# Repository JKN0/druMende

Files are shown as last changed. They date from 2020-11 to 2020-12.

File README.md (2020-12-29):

# druMende

Drumende is an analog drum machine in 70's style. All circuitry is designed so that it could have been built in the late 70's/early 80's.
All sound generators are analog, using transistors and op amps. Sequencer is without microcontroller, only 7400/4000-series discrete logic.

Soundgenerators are modeled according to classic drum machines and also newer designs:
- Boss DR-55: bass drum, snare drum, hi-hat, accent-circuit
- Korg KR-55: bass drum, snare drum, rimshot, claves, noise generator
- Andromeda Space Rockers by Eric Archer: hi-hat, tom hi, tom lo
- 7400 contest entry by Matt Sarnoff: sequencer

The goal has not been to duplicate the original circuits as close as possible. There are several modifications to original circuits.
Also sequencer has experienced serious modifications.

There are 10 sound generators. Because sequencer has only 6 voice channels + accent channel, sound for four channels is selectable.
Each channel level can be controlled with level control knobs. Also each channel has one controllable parameter, tuning or decay time.

Sequencer is 7 channel, 16 steps. Two 7 x 16 step patterns can be stored.

Demonstration video: https://youtu.be/f7uYuddqCkw

A more detailed build log is here: https://retroandreverse.blogspot.com/2020/12/analog-drums-beginnings-drumshave.html

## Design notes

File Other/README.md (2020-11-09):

# Audio and power

Enclosure for the drum machine is Nordmende Fidelio table radio from the 70's. 
Radio's audio amplifier and mains transformer are used as a part of the design.

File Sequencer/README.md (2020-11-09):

# Sequencer

Sequencer is  divided to two circuit boards

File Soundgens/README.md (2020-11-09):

# Sound generators

Sound generators are divided in four circuit boards:

- DR-55 soundgen
-- 3 generators: DR-55 BD, SD, HH
- KR-55 soundgen
-- 3 generators: KR-55 BD, SD; ASR MK2 HH
- Perc soundgen
-- 4 generators: KR-55 rimshot, claves; ASR MK1 hi-tom, lo-tom
- Main mixer
-- main mixer, accent submixer, accent circuit, noise generator

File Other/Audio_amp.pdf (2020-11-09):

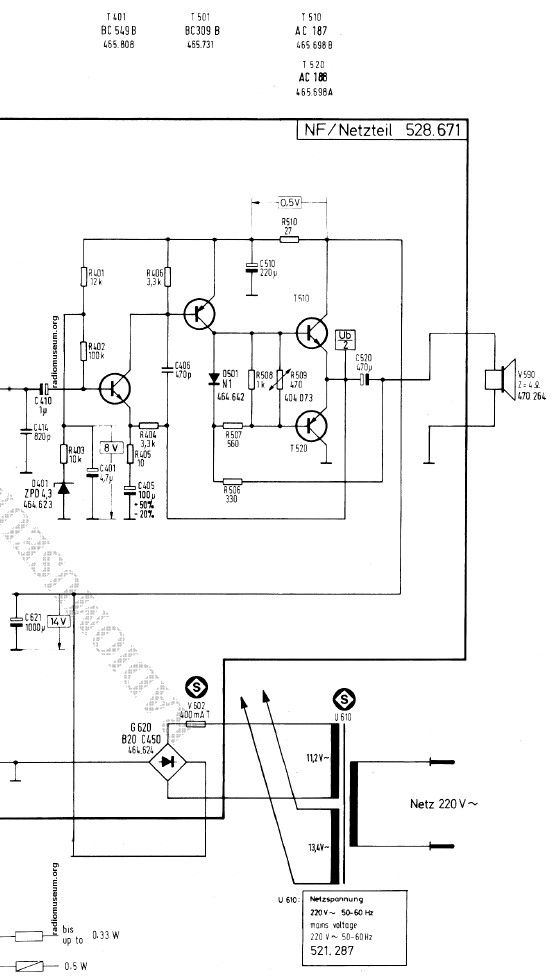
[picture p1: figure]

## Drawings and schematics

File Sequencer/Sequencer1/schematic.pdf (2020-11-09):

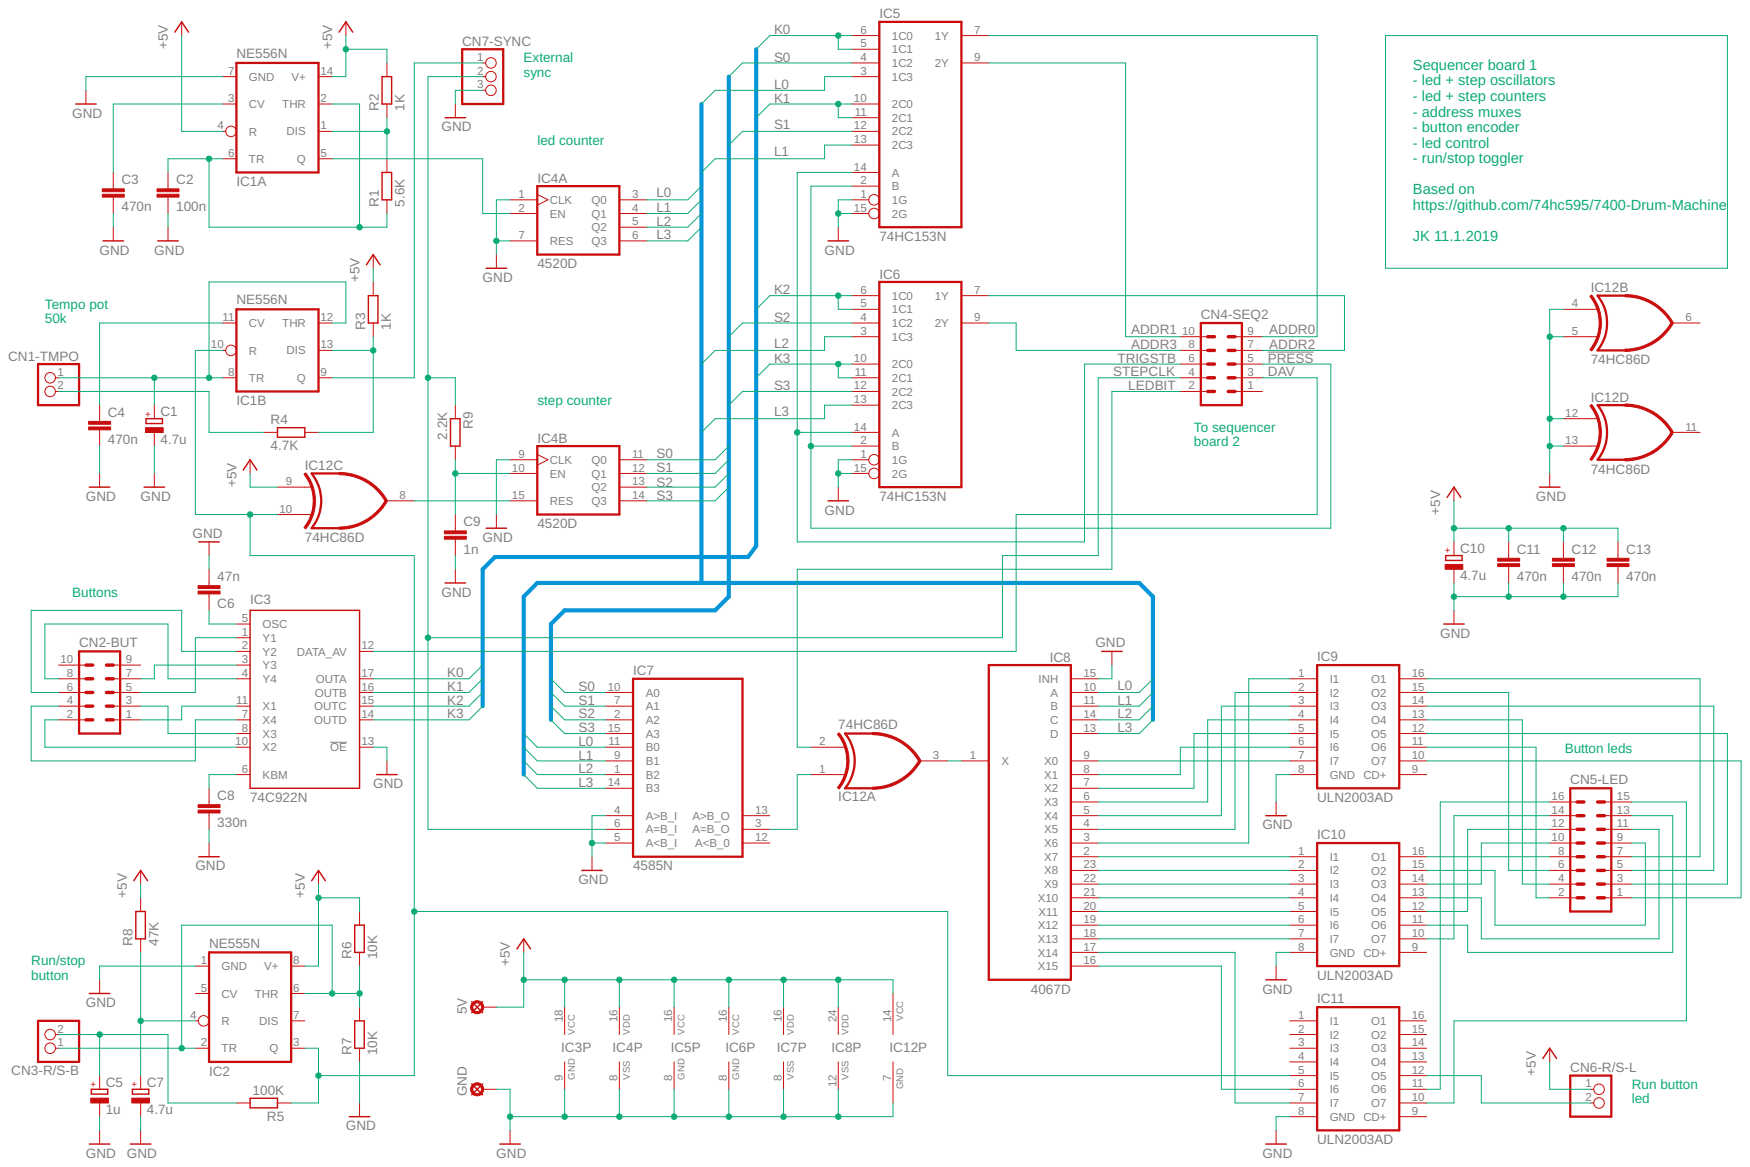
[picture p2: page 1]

Sequencer board 1
- led + step oscillators
- led + step counters
- address muxes
- button encoder
- led control - run/stop toggler Based on

https://github.com/74hc595/7400-Drum-Machine

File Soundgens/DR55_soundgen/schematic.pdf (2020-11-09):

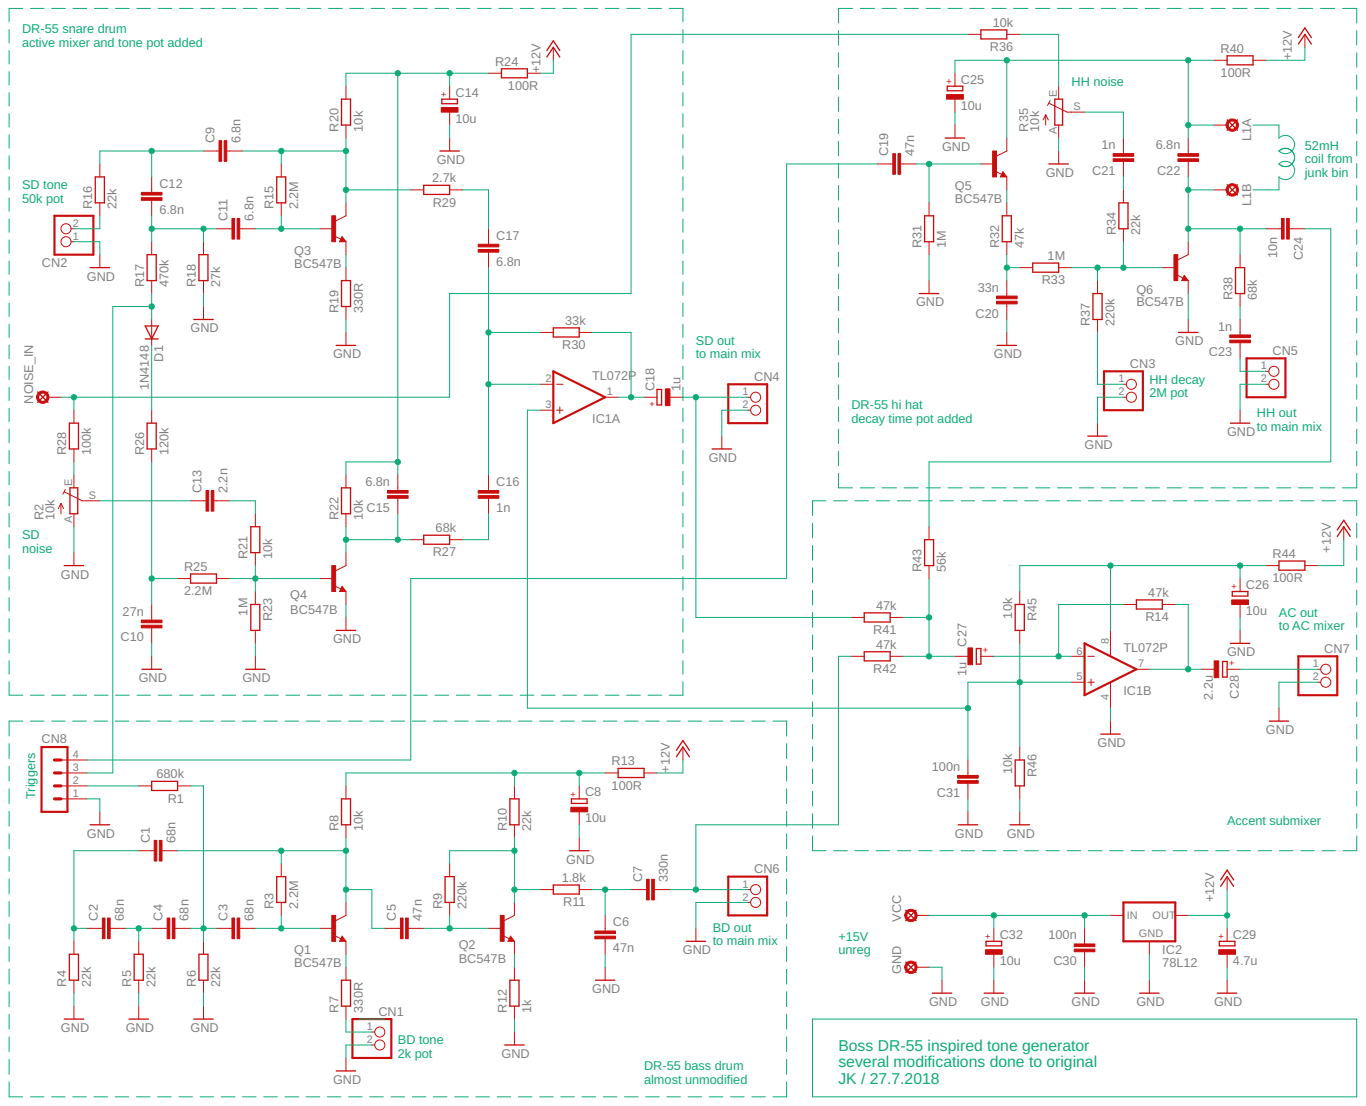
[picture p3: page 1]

DR-55 snare drum
active mixer and tone pot added

DR-55 hi hat decay time pot added

10k GND GND GND GND GND GND

Boss DR-55 inspired tone generator several modifications done to original

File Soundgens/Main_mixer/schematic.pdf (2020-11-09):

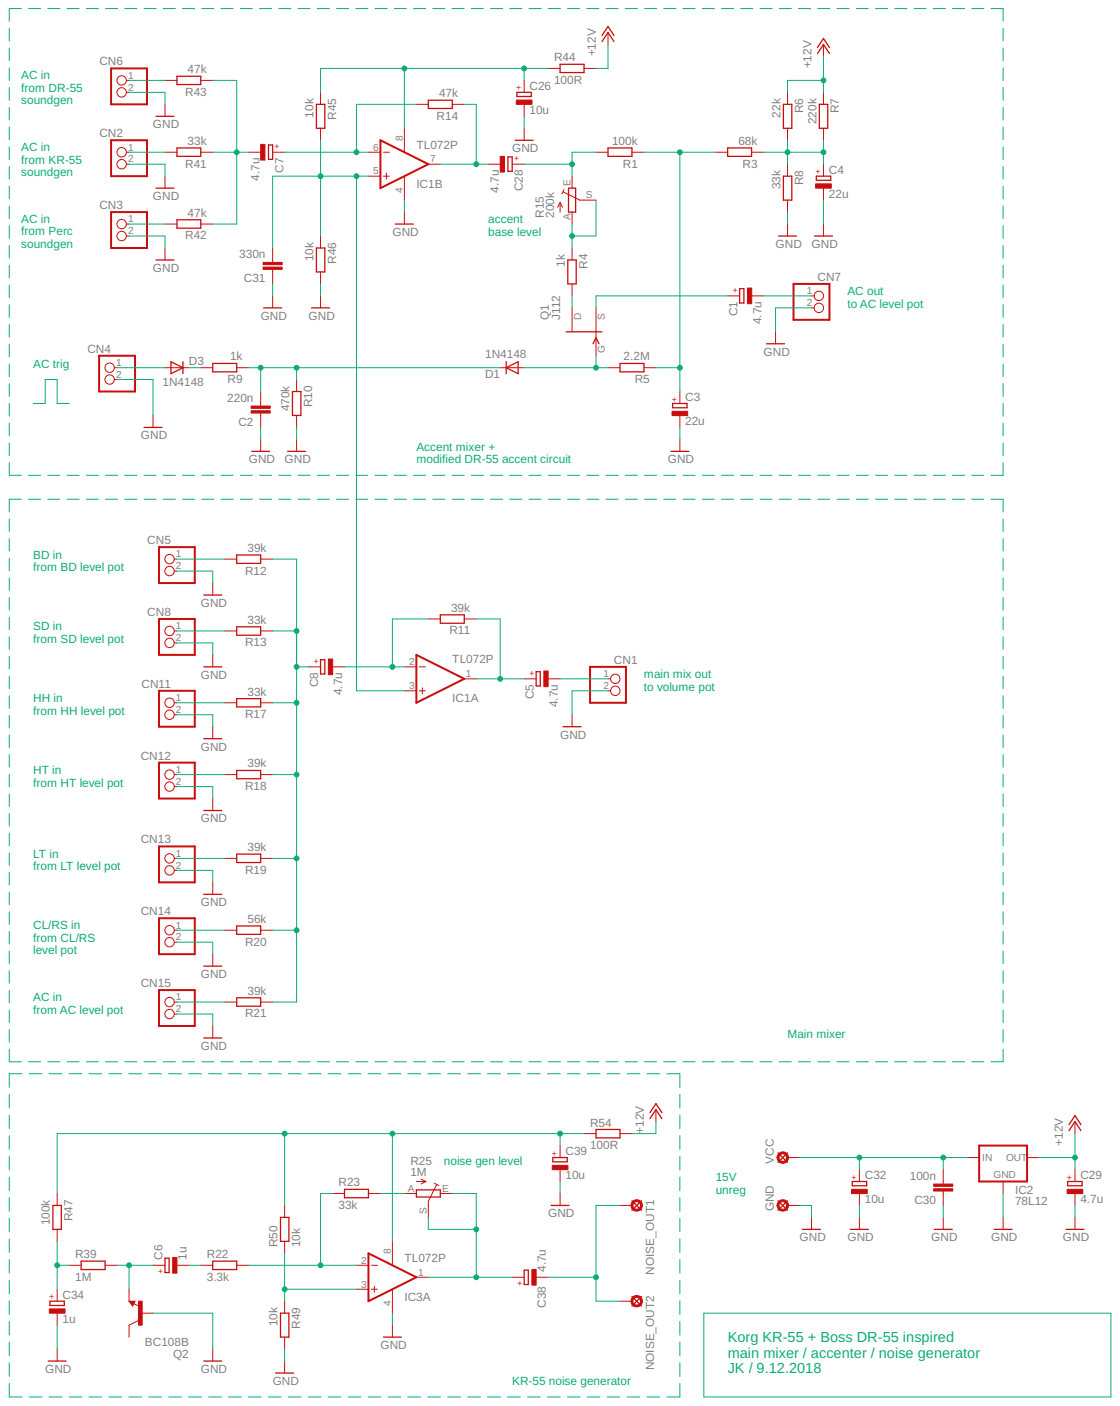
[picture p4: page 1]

AC out
to AC level pot

Accent mixer + modified DR-55 accent circuit

from BD level pot

from SD level pot HH in

from HH level pot HT in

from HT level pot LT in

from LT level pot CL/RS in

from CL/RS
level pot AC in

Korg KR-55 + Boss DR-55 inspired main mixer / accenter / noise generator JK / 9.12.2018

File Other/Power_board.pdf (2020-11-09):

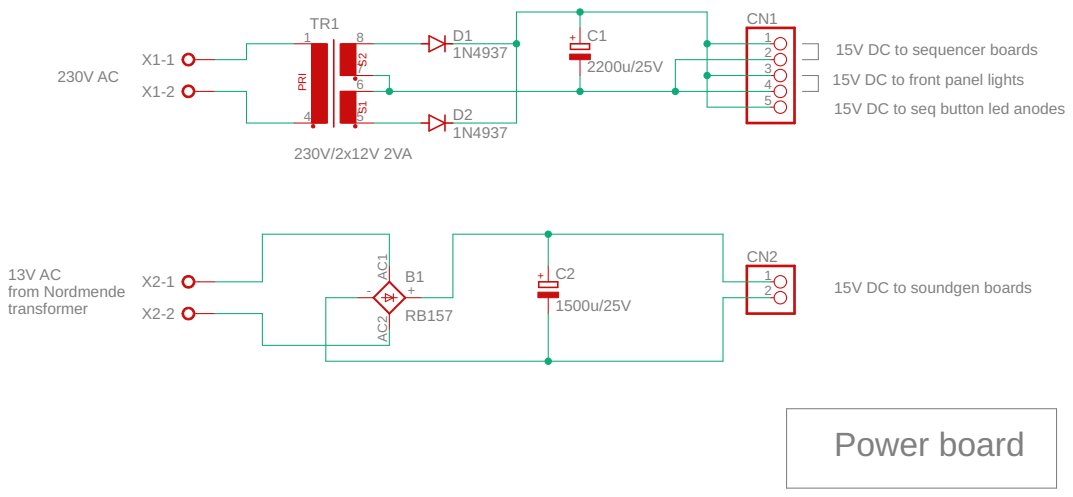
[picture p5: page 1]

15V DC to front panel lights 15V DC to seq button led anodes 15V DC to sequencer boards

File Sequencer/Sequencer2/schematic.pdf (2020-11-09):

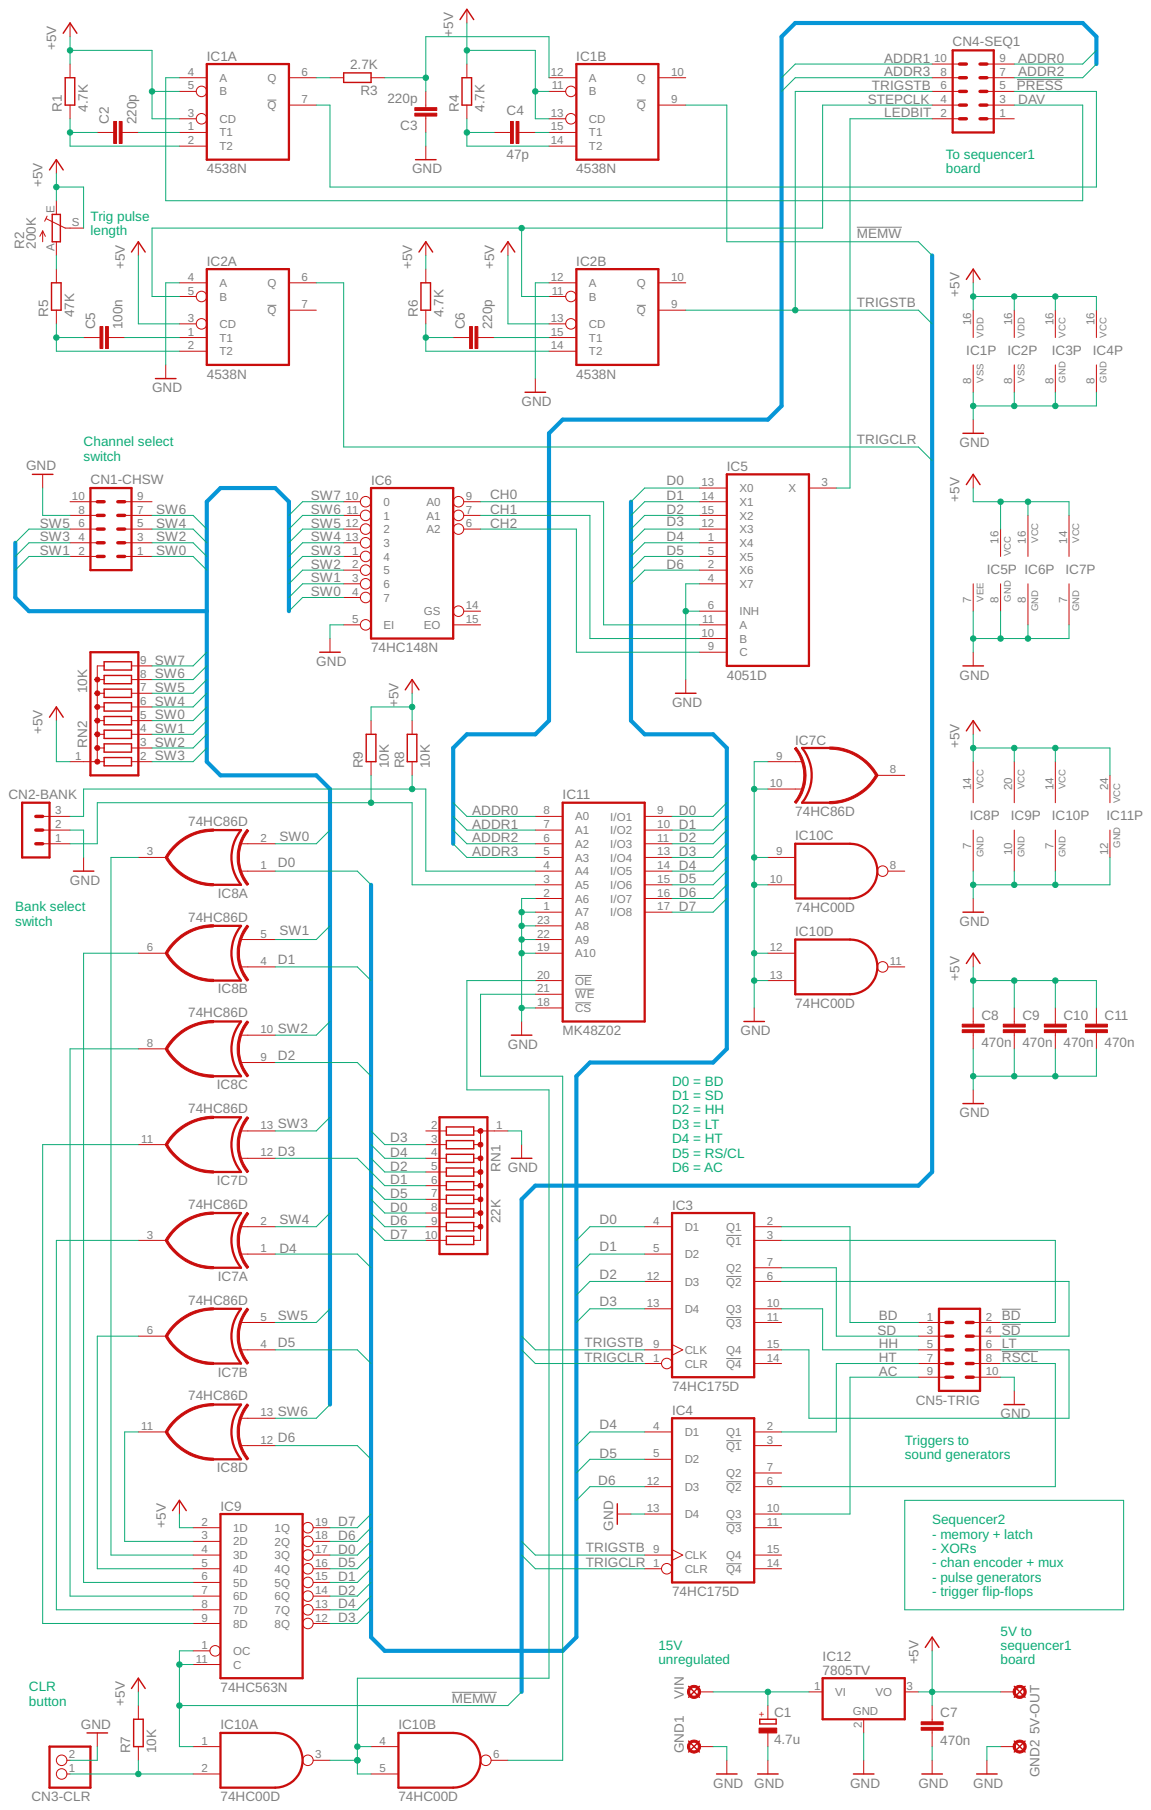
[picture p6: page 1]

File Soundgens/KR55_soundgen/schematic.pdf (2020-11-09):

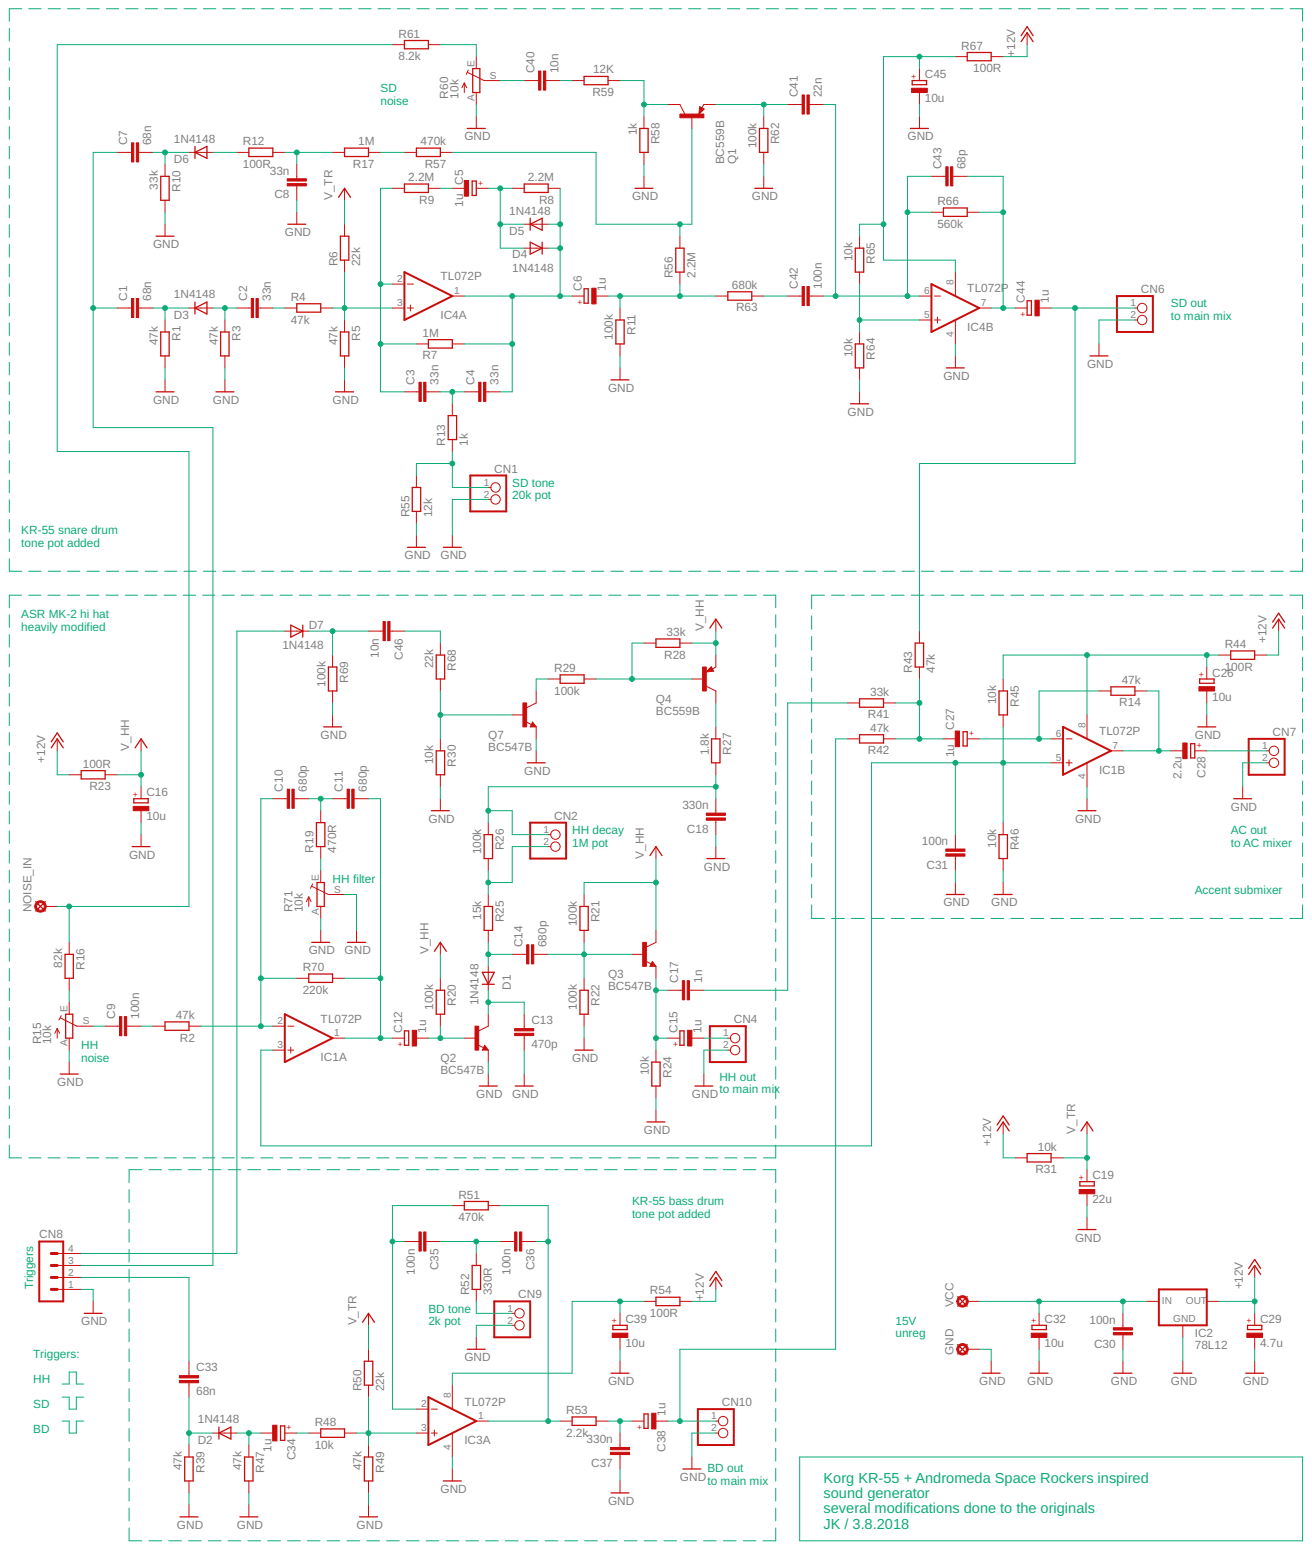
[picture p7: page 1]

KR-55 snare drum
tone pot added ASR MK-2 hi hat heavily modified

Korg KR-55 + Andromeda Space Rockers inspired
sound generator several modifications done to the originals

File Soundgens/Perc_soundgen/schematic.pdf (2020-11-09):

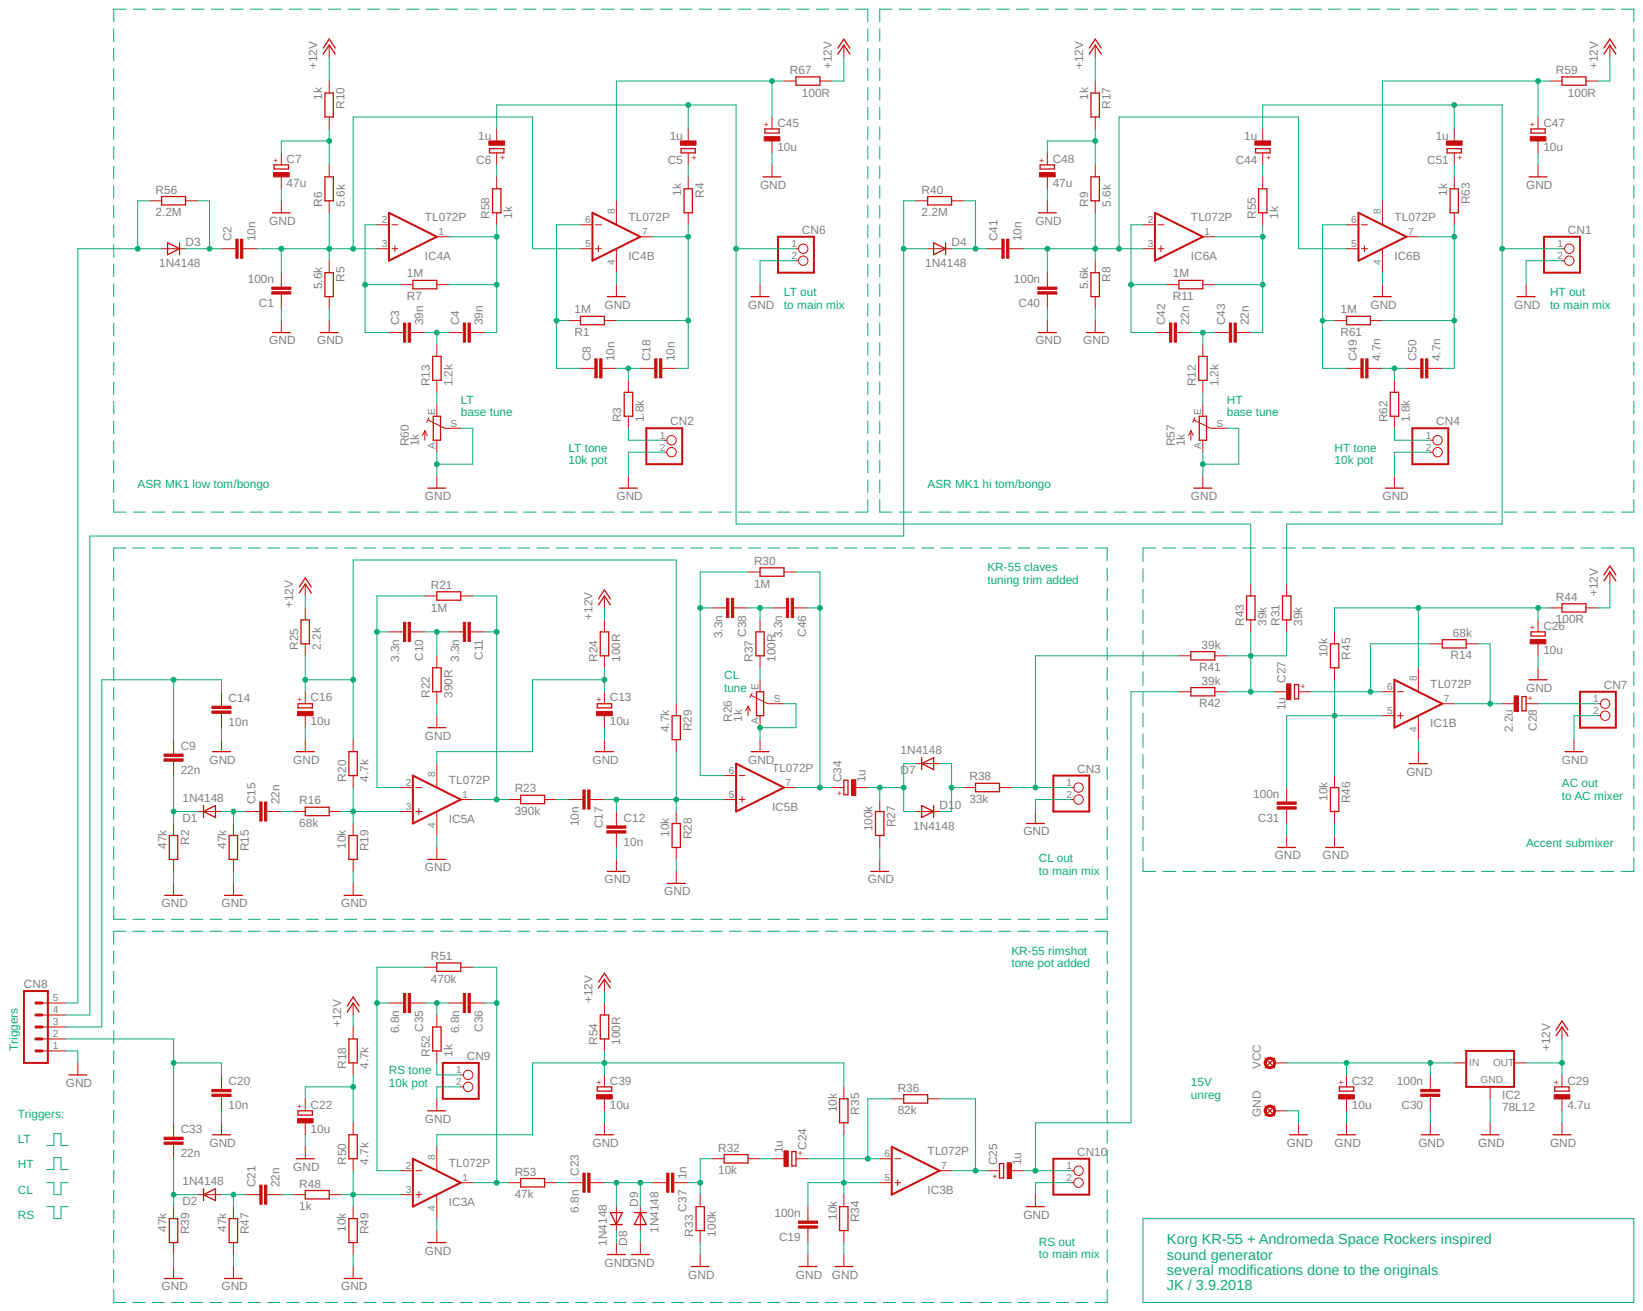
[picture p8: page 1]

ASR MK1 low tom/bongo

Korg KR-55 + Andromeda Space Rockers inspired
sound generator several modifications done to the originals

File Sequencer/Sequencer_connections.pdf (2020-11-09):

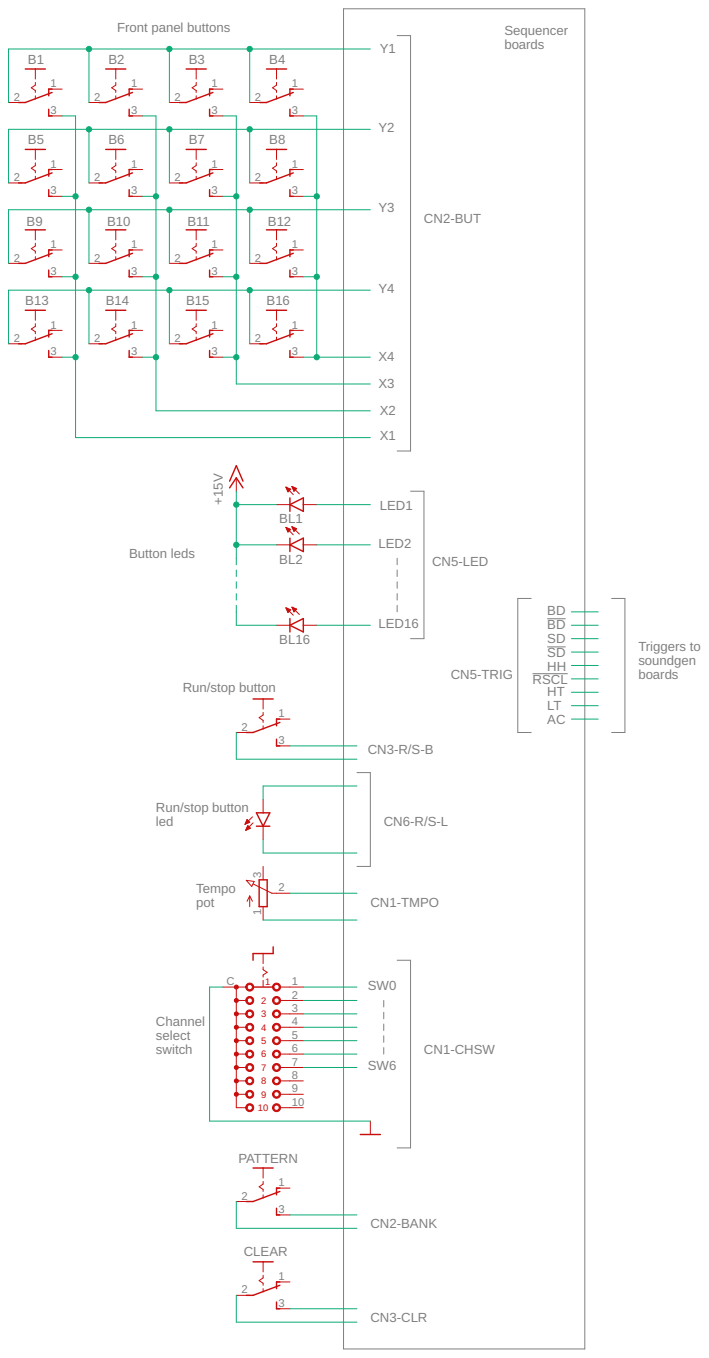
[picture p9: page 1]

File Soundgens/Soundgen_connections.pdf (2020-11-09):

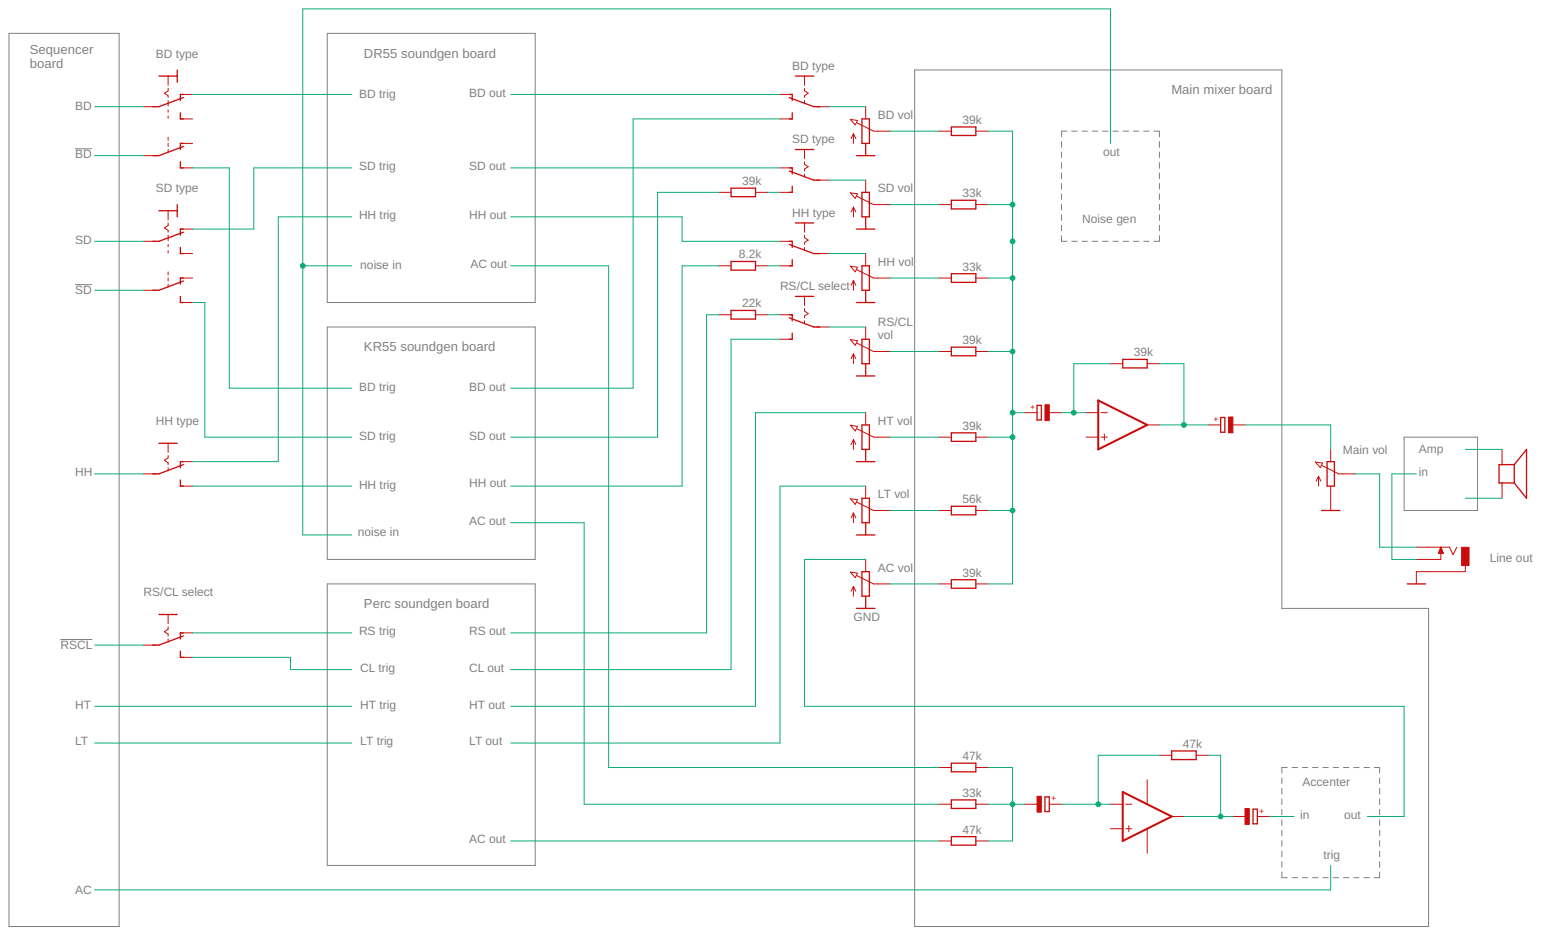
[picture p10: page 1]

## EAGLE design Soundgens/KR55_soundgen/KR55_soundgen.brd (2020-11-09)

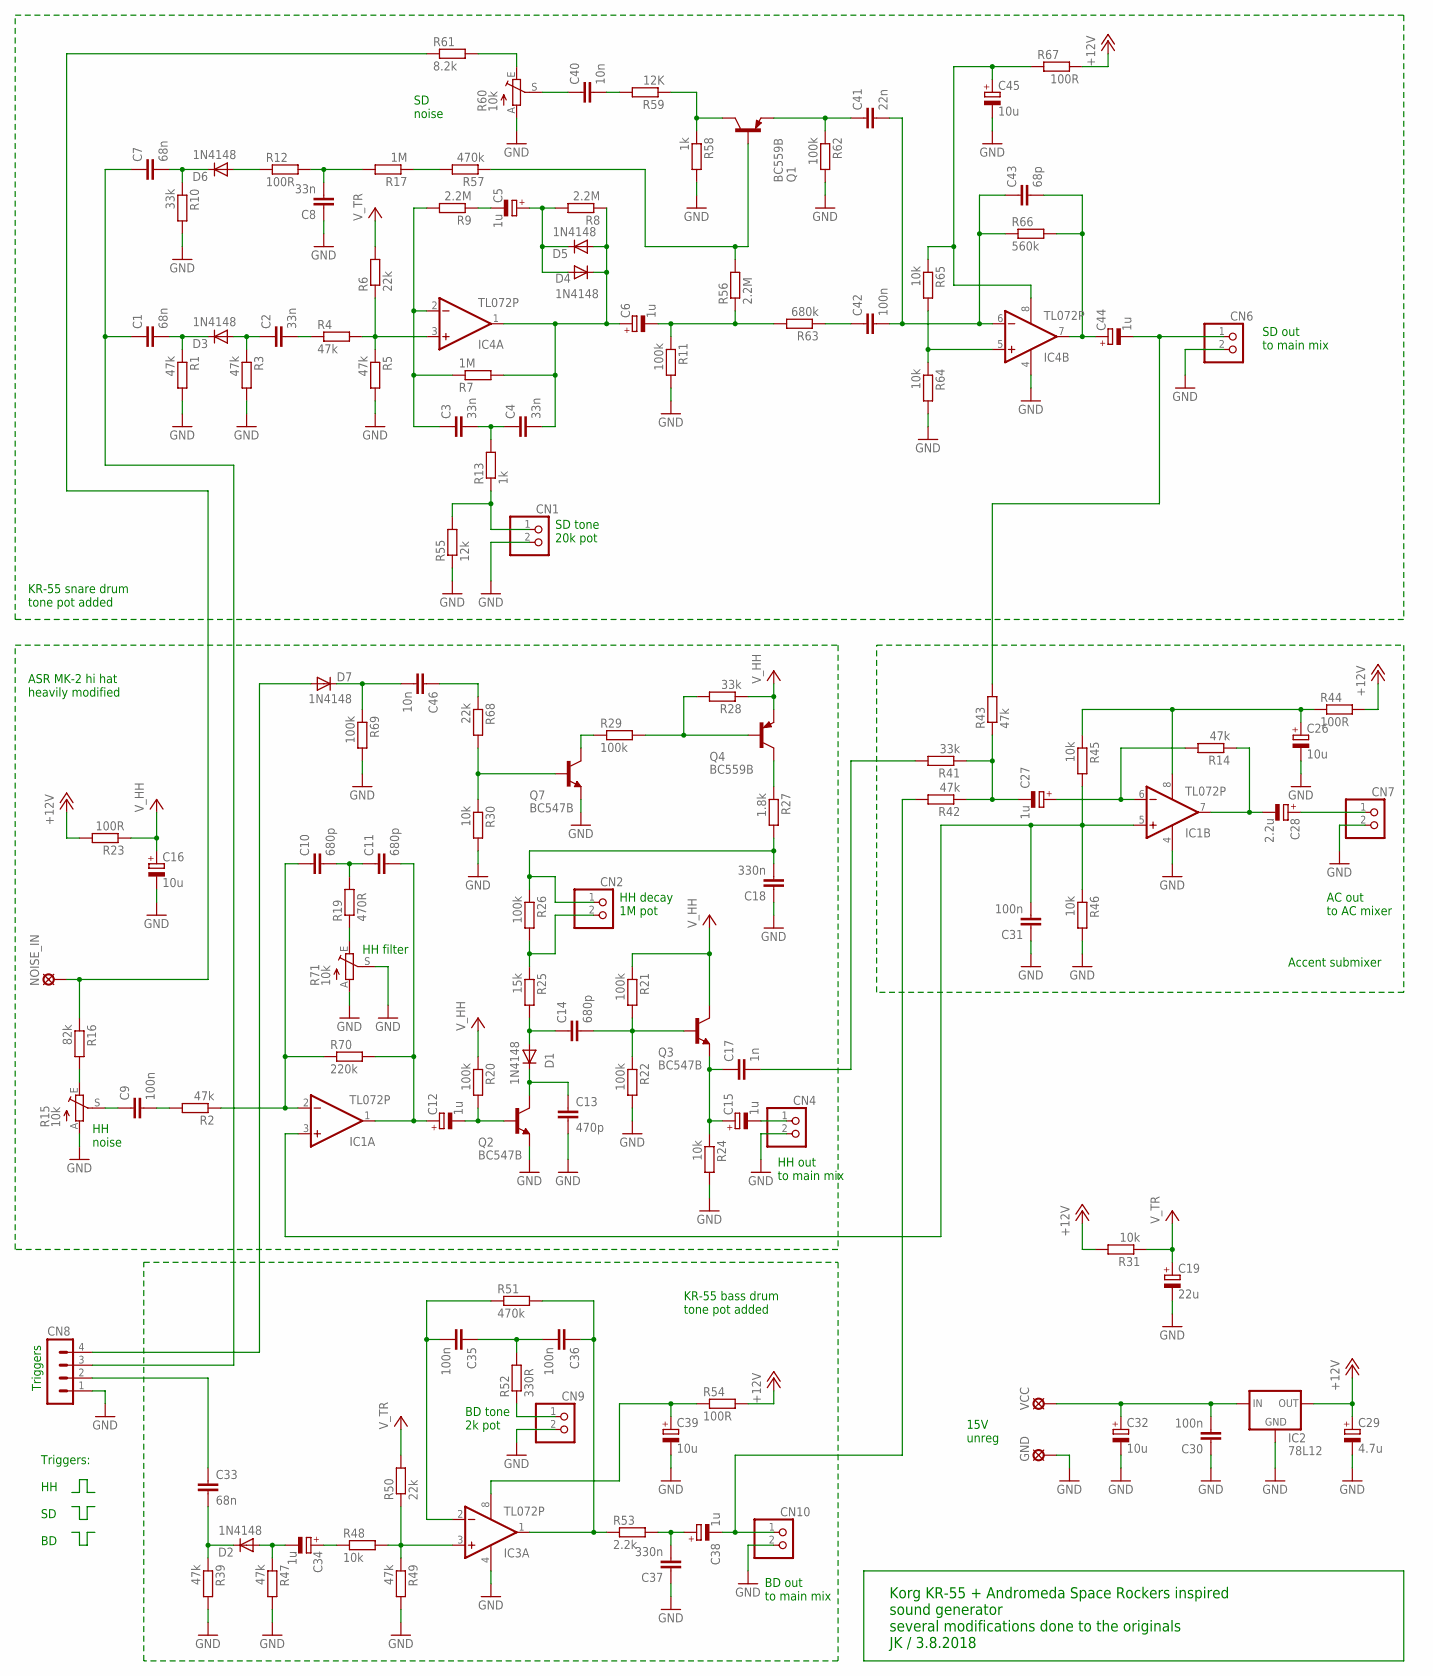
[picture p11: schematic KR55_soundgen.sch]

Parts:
C1, C7, C33: 68n; C0805
C2, C3, C4, C8: 33n; C0805
C5, C6, C12, C15, C27, C34, C38, C44: 1u; SMC_A
C9, C30, C31, C35, C36: 100n; C0805
C10, C11, C14: 680p; C0805
C13: 470p; C0805
C16, C32, C39, C45: 10u; E2,5-5
C17: 1n; C0805
C18, C37: 330n; C0805
C19: 22u; E2,5-5
C26: 10u; E5-5
C28: 2.2u; SMC_A
C29: 4.7u; SMC_A
C40: 10n; C1206
C41: 22n; C0805
C42: 100n; C050-024X044
C43: 68p; C0805
C46: 10n; C0805
CN1, CN2, CN4, CN6, CN7, CN9, CN10: PINHD-1X2; 1X02
CN8: MA04-1
D1, D2, D3, D4, D5, D6: 1N4148; SOD80C
D7: 1N4148; DO35-10
GND: LSP10
IC1, IC3, IC4: TL072P; DIL08
IC2: 78L12; 78LXX
NOISE_IN: LSP10
Q1, Q4: BC559B; TO92-EBC
Q2, Q3, Q7: BC547B; TO92
R1, R2, R3, R4, R5, R14, R39, R42, R43, R47, R49: 47k; R0805
R6, R50, R68: 22k; R0805
R7, R17: 1M; R0805
R8, R9, R56: 2.2M; R0805
R10, R28, R41: 33k; R0805
R11, R21, R22, R26, R29, R62, R69: 100k; R0805
R12, R23, R67: 100R; R0805
R13, R58: 1k; R0805
R15, R60, R71: 10k; S63X
R16: 82k; R0805
R19: 470R; 0207/10
R20: 100k; 0207/10
R24, R30, R31, R45, R46, R48, R64, R65: 10k; R0805
R25: 15k; 0207/10
R27: 1.8k; 0207/10
R44, R54: 100R; 0207/10
R51, R57: 470k; R0805
R52: 330R; R0805
R53: 2.2k; 0207/10
R55: 12k; R0805
R59: 12K; R0805
R61: 8.2k; R0805
R63: 680k; R0805
R66: 560k; R0805
R70: 220k; R0805
VCC: LSP10

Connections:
+12V: C29.+, IC2.OUT, R23.2, R31.2, R44.2, R54.2, R67.2
+15V: C30.2, C32.+, IC2.IN, VCC.MP
GND: C8.1, C13.2, C16.-, C18.1, C19.-, C26.-, C29.-, C30.1, C31.1, C32.-, C37.1, C39.-, C45.-, CN1.2, CN4.2, CN6.2, CN7.2, CN8.1, CN9.2, CN10.2, GND.MP, IC1.4 (V-), IC2.GND, IC3.4 (V-), IC4.4 (V-), Q2.1 (E), Q7.1 (E), R1.2, R3.2, R5.2, R10.2, R11.2, R15.A, R22.2, R24.2, R30.2, R39.2, R46.2, R47.2, R49.2, R55.1, R58.2, R60.A, R62.2, R64.2, R69.2, R71.A, R71.S
unnamed: C3.1, IC4.2 (-IN), R7.1, R9.2
unnamed: C4.2, C6.+, D4.C, D5.A, IC4.1 (OUT), R7.2, R8.1
unnamed: IC4.3 (+IN), R4.2, R5.1, R6.1
unnamed: C2.2, R4.1
unnamed: C2.1, D3.A, R3.1
unnamed: C1.2, D3.C, R1.1
unnamed: R15.E, R16.2
unnamed: CN1.1, R13.1, R55.2
unnamed: C9.1, R15.S
unnamed: C5.-, R9.1
unnamed: C5.+, D4.A, D5.C, R8.2
unnamed: R60.E, R61.2
unnamed: C9.2, R2.2
unnamed: R19.1, R71.E
unnamed: C12.-, Q2.2 (B), R20.2
unnamed: C11.2, C12.+, IC1.1 (OUT), R70.2
unnamed: C13.1, D1.C, Q2.3 (C)
unnamed: C10.1, IC1.2 (-IN), R2.1, R70.1
unnamed: C10.2, C11.1, R19.2
unnamed: C14.1, D1.A, R25.2
unnamed: C14.2, Q3.2 (B), R21.2, R22.1
unnamed: C41.2, C42.2, C43.1, IC4.6 (-IN), R66.1
unnamed: C35.2, IC3.2 (-IN), R51.1
unnamed: C15.+, C17.1, Q3.1 (E), R24.1
unnamed: CN2.2, R25.1, R26.2
unnamed: C18.2, CN2.1, R26.1, R27.2
unnamed: C8.2, R12.2, R17.2
unnamed: Q4.C, R27.1
unnamed: R17.1, R57.2
unnamed: C27.-, R41.1, R42.1, R43.1
unnamed: C28.-, IC1.7 (OUT), R14.1
unnamed: C27.+, IC1.6 (-IN), R14.2
unnamed: C36.1, IC3.1 (OUT), R51.2, R53.1
unnamed: C35.1, C36.2, R52.2
unnamed: CN9.1, R52.1
unnamed: IC3.3 (+IN), R48.2, R49.1, R50.1
unnamed: C34.+, R48.1
unnamed: C34.-, D2.A, R47.1
unnamed: C33.2, D2.C, R39.1
unnamed: C37.2, C38.+, R53.2
unnamed: C3.2, C4.1, R13.2
unnamed: C40.1, R60.S
unnamed: D6.A, R12.1
unnamed: C7.2, D6.C, R10.1
unnamed: C40.2, R59.2
unnamed: Q1.C, R58.1, R59.1
unnamed: Q1.B, R56.2, R57.1
unnamed: C6.-, R11.1, R56.1, R63.2
unnamed: C42.1, R63.1
unnamed: C41.1, Q1.E, R62.1
unnamed: IC4.5 (+IN), R64.1, R65.2
unnamed: C43.2, C44.+, IC4.7 (OUT), R66.2
unnamed: C45.+, IC4.8 (V+), R65.1, R67.1
unnamed: Q4.B, R28.2, R29.2
unnamed: Q7.3 (C), R29.1
unnamed: Q7.2 (B), R30.1, R68.2
unnamed: C46.1, R68.1
unnamed: C46.2, D7.C, R69.1
NOISE_IN: NOISE_IN.MP, R16.1, R61.1
OUT_AC: C28.+, CN7.1
OUT_BD: C38.-, CN10.1, R42.2
OUT_HH: C15.-, CN4.1
OUT_HH_AC: C17.2, R41.2
OUT_SD: C44.-, CN6.1, R43.2
TRIG_BD: C33.1, CN8.2
TRIG_HH: CN8.4, D7.A
TRIG_SD: C1.1, C7.1, CN8.3
V_BD: C39.+, IC3.8 (V+), R54.1
V_HH: C16.+, Q3.3 (C), Q4.E, R20.1, R21.1, R23.1, R28.1
V_MX: C26.+, IC1.8 (V+), R44.1, R45.1
V_MX/2: C31.2, IC1.3 (+IN), IC1.5 (+IN), R45.2, R46.1
V_TR: C19.+, R6.2, R31.1, R50.2

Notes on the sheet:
Triggers
SD tone 20k pot
HH decay 1M pot
HH out to main mix
AC out to AC mixer
15V unreg
KR-55 bass drum tone pot added
KR-55 snare drum tone pot added
ASR MK-2 hi hat heavily modified
Accent submixer
Korg KR-55 + Andromeda Space Rockers inspired sound generator several modifications done to the originals JK / 3.8.2018
SD noise
BD out to main mix
BD tone 2k pot
SD out to main mix
HH noise
HH filter
Triggers: HH SD BD

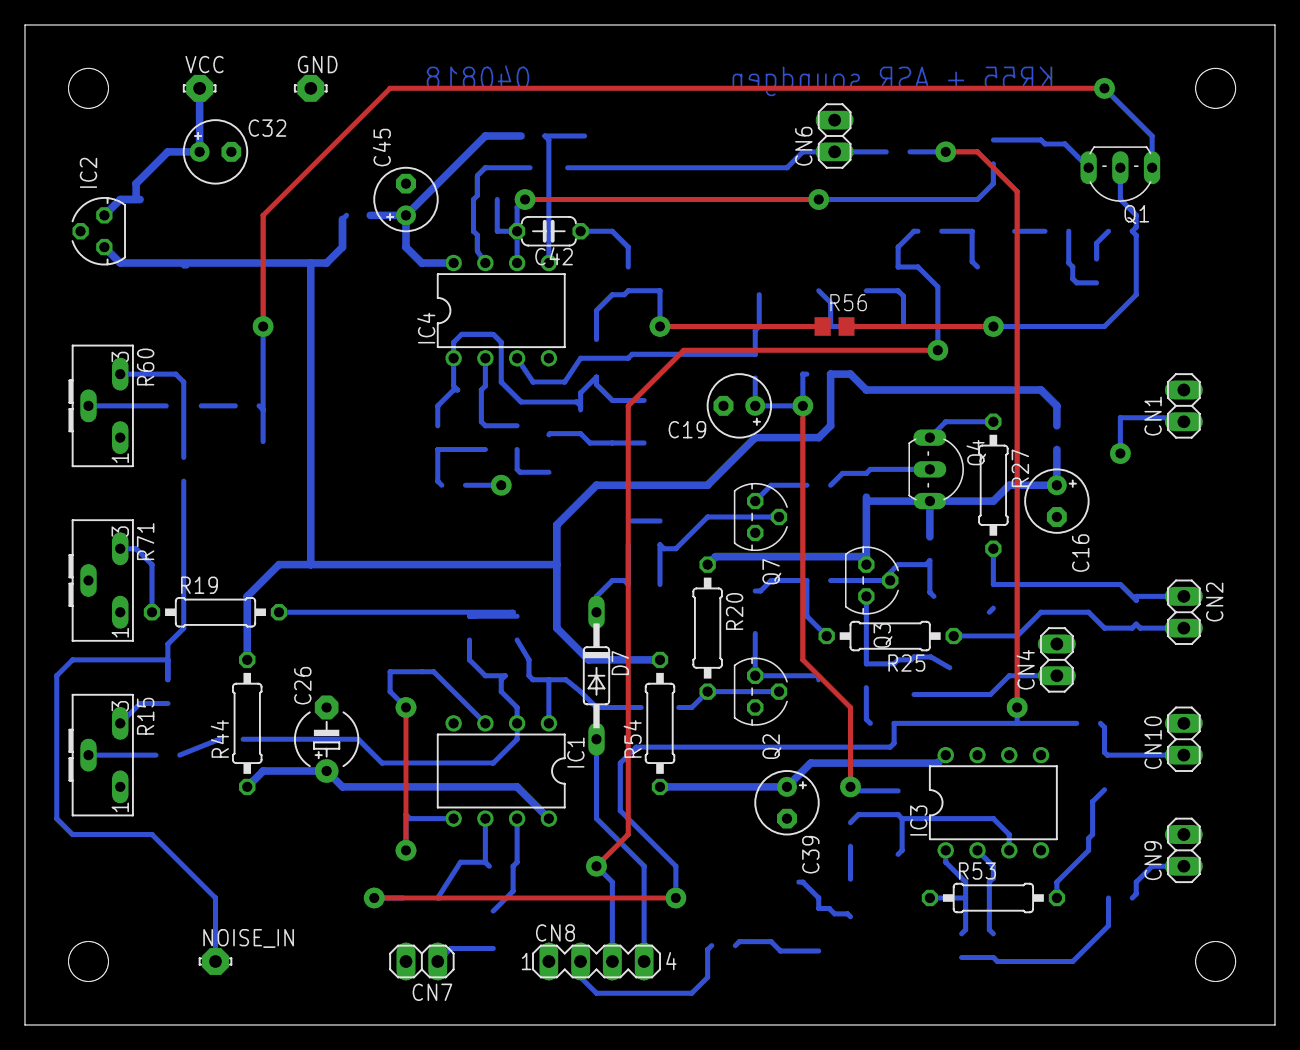
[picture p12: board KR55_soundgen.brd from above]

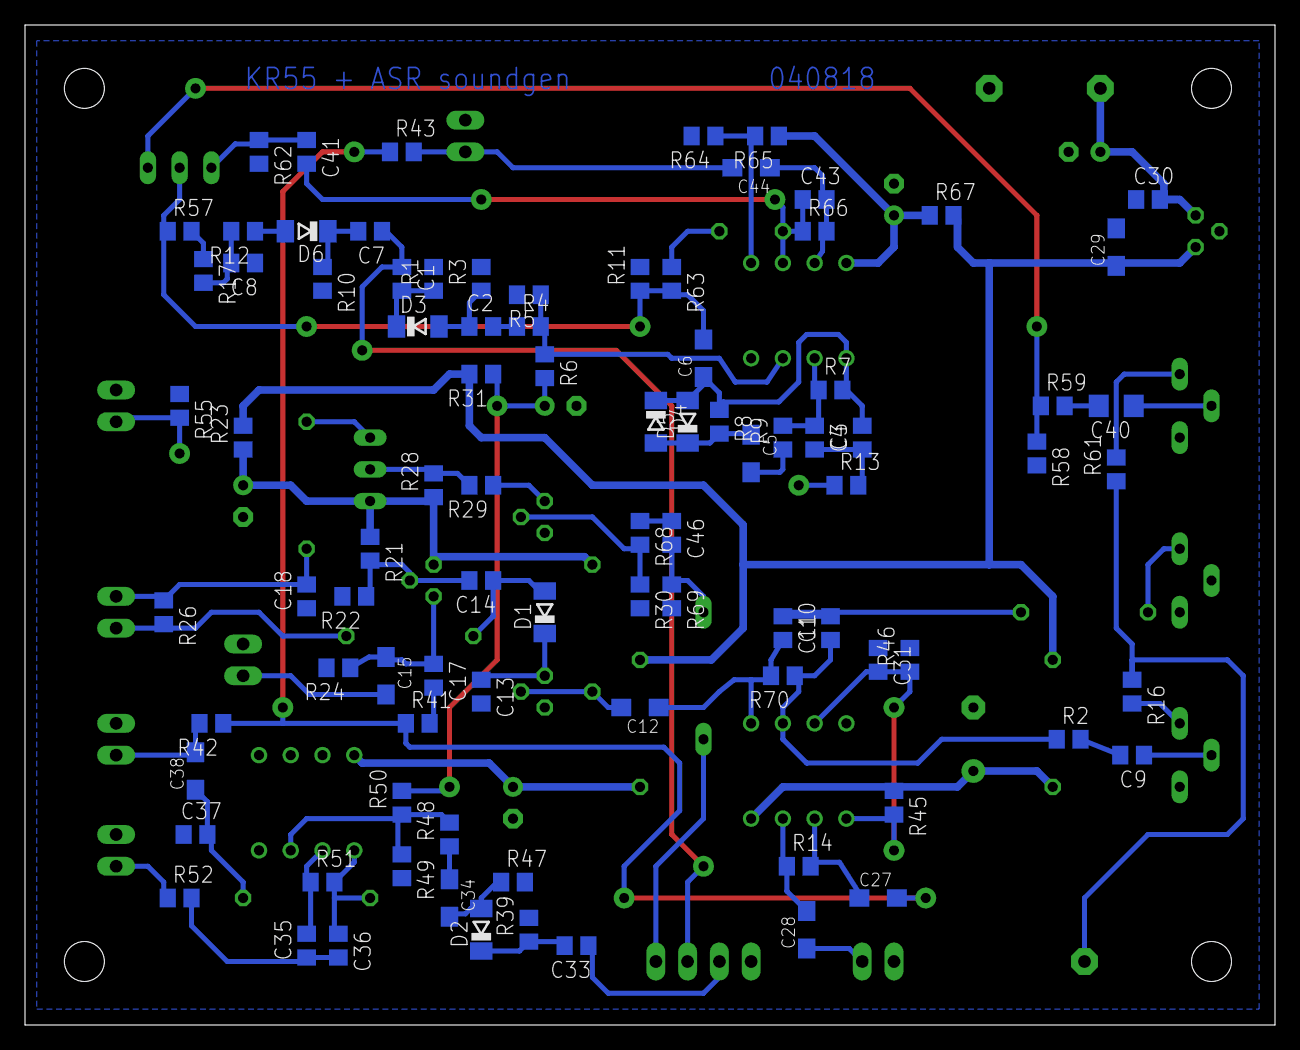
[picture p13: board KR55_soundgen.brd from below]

Board: 2 copper layers, 100.0 x 80.0 mm, 129 parts (90 on the bottom side), 75 nets.

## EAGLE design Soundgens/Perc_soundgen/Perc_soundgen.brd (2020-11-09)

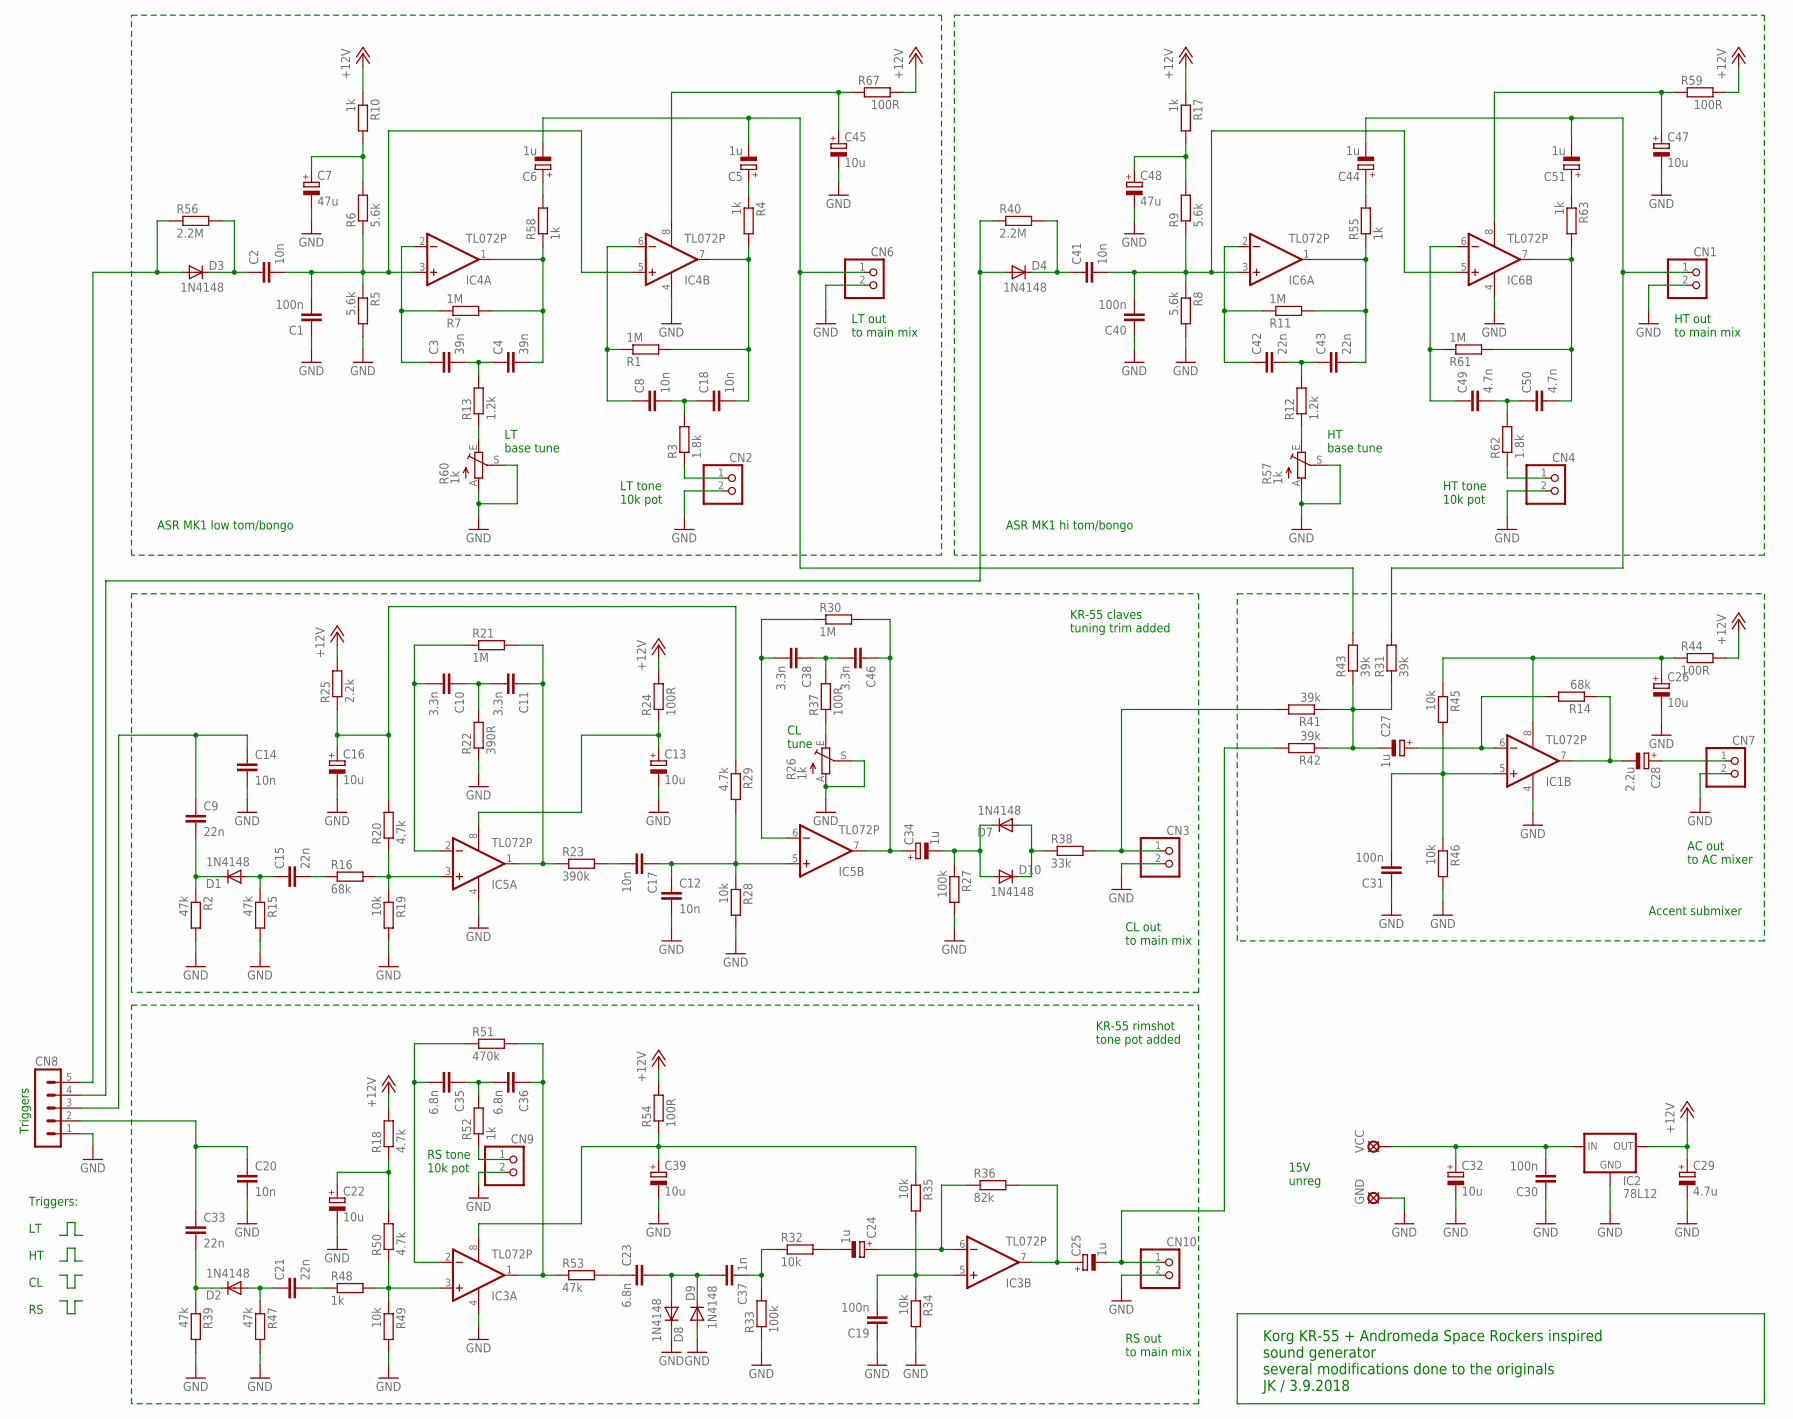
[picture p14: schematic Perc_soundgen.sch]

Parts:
C1, C19, C30, C31, C40: 100n; C0805
C2, C8, C12, C14, C17, C18, C20, C41: 10n; C0603
C3, C4: 39n; C0805
C5, C6, C24, C25, C27, C34, C44, C51: 1u; SMC_A
C7, C48: 47u; E2,5-5
C9, C15, C21, C42, C43: 22n; C0805
C10, C11, C38, C46: 3.3n; C0805
C13, C16, C22, C26, C32, C39, C45, C47: 10u; E2,5-5
C23, C35, C36: 6.8n; C0805
C28: 2.2u; SMC_A
C29: 4.7u; SMC_A
C33: 22n; C075-032X103
C37: 1n; C0805
C49, C50: 4.7n; C0805
CN1, CN2, CN3, CN4, CN6, CN7, CN9, CN10: PINHD-1X2; 1X02
CN8: MA05-1
D1, D2, D3, D4, D7, D8, D9, D10: 1N4148; SOD80C
GND: LSP10
IC1, IC3, IC4, IC5, IC6: TL072P; DIL08
IC2: 78L12; 78LXX
R1, R7, R11, R21, R30, R61: 1M; R0805
R2, R15, R39, R47: 47k; R0805
R3, R62: 1.8k; R0805
R4, R55, R58, R63: 1k; 0207/10
R5, R6, R8, R9: 5.6k; R0805
R10, R17, R48, R52: 1k; R0805
R12: 1.2k; R0805
R13: 1.2k; 0207/12
R14, R16: 68k; R0805
R18, R29: 4.7k; 0207/10
R19, R28, R32, R34, R35, R45, R46, R49: 10k; R0805
R20, R50: 4.7k; R0805
R22: 390R; R1206
R23: 390k; 0207/10
R24, R37, R44, R54, R59, R67: 100R; R0805
R25: 2.2k; R0805
R26, R57, R60: 1k; S63X
R27, R33: 100k; R0805
R31, R41, R42, R43: 39k; R0805
R36: 82k; R0805
R38: 33k; R0805
R40, R56: 2.2M; R0805
R51: 470k; R0805
R53: 47k; 0207/10
VCC: LSP10

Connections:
+12V: C29.+, IC2.OUT, R10.1, R17.1, R18.2, R24.2, R25.2, R44.2, R54.2, R59.2, R67.2
+15V: C30.2, C32.+, IC2.IN, VCC.MP
GND: C1.1, C7.-, C12.2, C13.-, C14.2, C16.-, C19.1, C20.2, C22.-, C26.-, C29.-, C30.1, C31.1, C32.-, C39.-, C40.1, C45.-, C47.-, C48.-, CN1.2, CN2.2, CN3.2, CN4.2, CN6.2, CN7.2, CN8.1, CN9.2, CN10.2, D8.C, D9.A, GND.MP, IC1.4 (V-), IC2.GND, IC3.4 (V-), IC4.4 (V-), IC5.4 (V-), IC6.4 (V-), R2.2, R5.2, R8.2, R15.2, R19.2, R22.1, R26.A, R26.S, R27.2, R28.2, R33.1, R34.2, R39.2, R46.2, R47.2, R49.2, R57.A, R57.S, R60.A, R60.S
unnamed: C3.1, IC4.2 (-IN), R7.1
unnamed: C4.2, IC4.1 (OUT), R7.2, R58.1
unnamed: C1.2, C2.2, IC4.3 (+IN), IC4.5 (+IN), R5.1, R6.1
unnamed: C6.+, R58.2
unnamed: C7.+, R6.2, R10.2
unnamed: C18.2, IC4.7 (OUT), R1.2, R4.2
unnamed: R13.1, R60.E
unnamed: C10.2, IC5.2 (-IN), R21.1
unnamed: C2.1, D3.C, R56.2
unnamed: C23.2, R53.2
unnamed: CN2.1, R3.1
unnamed: C11.1, IC5.1 (OUT), R21.2, R23.1
unnamed: C10.1, C11.2, R22.2
unnamed: R26.E, R37.1
unnamed: IC5.3 (+IN), R16.2, R19.1, R20.1
unnamed: C15.2, R16.1
unnamed: C15.1, D1.A, R15.1
unnamed: C9.2, D1.C, R2.1
unnamed: C16.+, R20.2, R25.1, R29.1
unnamed: C38.2, IC5.6 (-IN), R30.1
unnamed: C8.1, IC4.6 (-IN), R1.1
unnamed: C35.2, IC3.2 (-IN), R51.1
unnamed: C12.1, C17.1, IC5.5 (+IN), R28.1, R29.2
unnamed: C34.-, D7.C, D10.A, R27.1
unnamed: C34.+, C46.1, IC5.7 (OUT), R30.2
unnamed: C8.2, C18.1, R3.2
unnamed: C17.2, R23.2
unnamed: C24.+, IC3.6 (-IN), R36.1
unnamed: C22.+, R18.1, R50.2
unnamed: C24.-, R32.2
unnamed: C19.2, IC3.5 (+IN), R34.1, R35.2
unnamed: D7.A, D10.C, R38.1
unnamed: C37.1, R32.1, R33.2
unnamed: C27.-, R31.1, R41.1, R42.1, R43.1
unnamed: C28.-, IC1.7 (OUT), R14.1
unnamed: C27.+, IC1.6 (-IN), R14.2
unnamed: C23.1, C37.2, D8.A, D9.C
unnamed: C36.1, IC3.1 (OUT), R51.2, R53.1
unnamed: C35.1, C36.2, R52.2
unnamed: CN9.1, R52.1
unnamed: IC3.3 (+IN), R48.2, R49.1, R50.1
unnamed: C21.2, R48.1
unnamed: C21.1, D2.A, R47.1
unnamed: C33.2, D2.C, R39.1
unnamed: C38.1, C46.2, R37.2
unnamed: C25.+, IC3.7 (OUT), R36.2
unnamed: C3.2, C4.1, R13.2
unnamed: C5.+, R4.1
unnamed: C43.2, IC6.1 (OUT), R11.2, R55.1
unnamed: C40.2, C41.2, IC6.3 (+IN), IC6.5 (+IN), R8.1, R9.1
unnamed: C42.1, IC6.2 (-IN), R11.1
unnamed: C42.2, C43.1, R12.2
unnamed: C47.+, IC6.8 (V+), R59.1
unnamed: C48.+, R9.2, R17.2
unnamed: C41.1, D4.C, R40.2
unnamed: C50.2, IC6.7 (OUT), R61.2, R63.2
unnamed: CN4.1, R62.1
unnamed: C49.1, IC6.6 (-IN), R61.1
unnamed: C49.2, C50.1, R62.2
unnamed: R12.1, R57.E
unnamed: C45.+, IC4.8 (V+), R67.1
unnamed: C44.+, R55.2
unnamed: C51.+, R63.1
OUT_AC: C28.+, CN7.1
OUT_CL: CN3.1, R38.2, R41.2
OUT_HT: C44.-, C51.-, CN1.1, R31.2
OUT_LT: C5.-, C6.-, CN6.1, R43.2
OUT_RS: C25.-, CN10.1, R42.2
TRIG_CL: C9.1, C14.1, CN8.3
TRIG_HT: CN8.4, D4.A, R40.1
TRIG_LT: CN8.5, D3.A, R56.1
TRIG_RS: C20.1, C33.1, CN8.2
V_BD: C39.+, IC3.8 (V+), R35.1, R54.1
V_BD1: C13.+, IC5.8 (V+), R24.1
V_MX: C26.+, IC1.8 (V+), R44.1, R45.1
V_MX/2: C31.2, IC1.5 (+IN), R45.2, R46.1

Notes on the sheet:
Triggers
AC out to AC mixer
15V unreg
KR-55 rimshot tone pot added
ASR MK1 low tom/bongo
Accent submixer
Korg KR-55 + Andromeda Space Rockers inspired sound generator several modifications done to the originals JK / 3.9.2018
LT base tune
RS out to main mix
RS tone 10k pot
LT out to main mix
Triggers: LT HT CL RS
KR-55 claves tuning trim added
CL out to main mix
CL tune
LT tone 10k pot
ASR MK1 hi tom/bongo
HT base tune
HT out to main mix
HT tone 10k pot

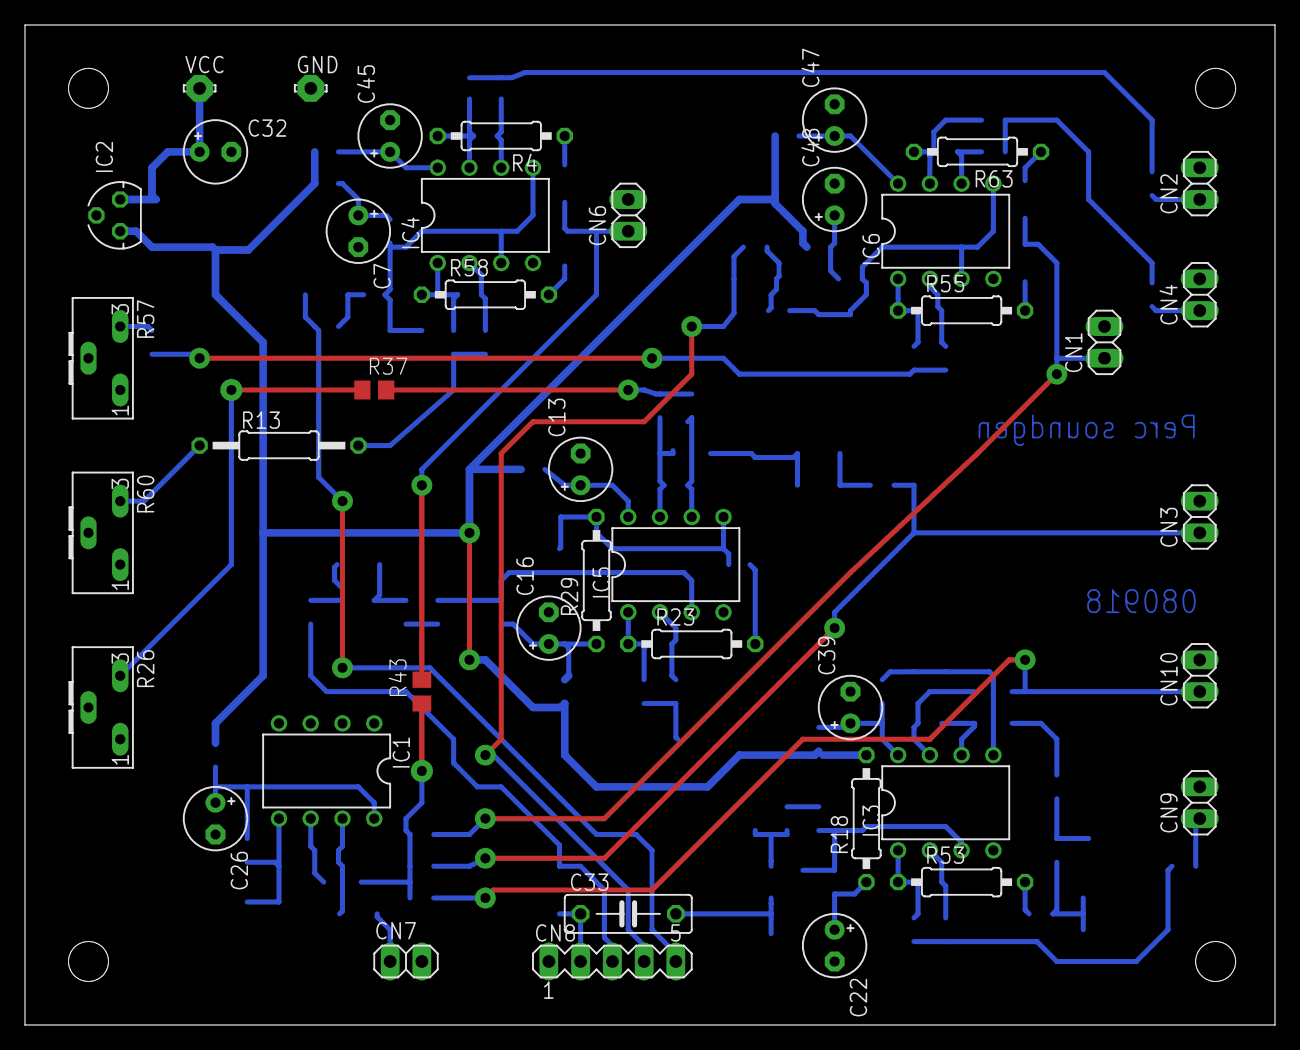
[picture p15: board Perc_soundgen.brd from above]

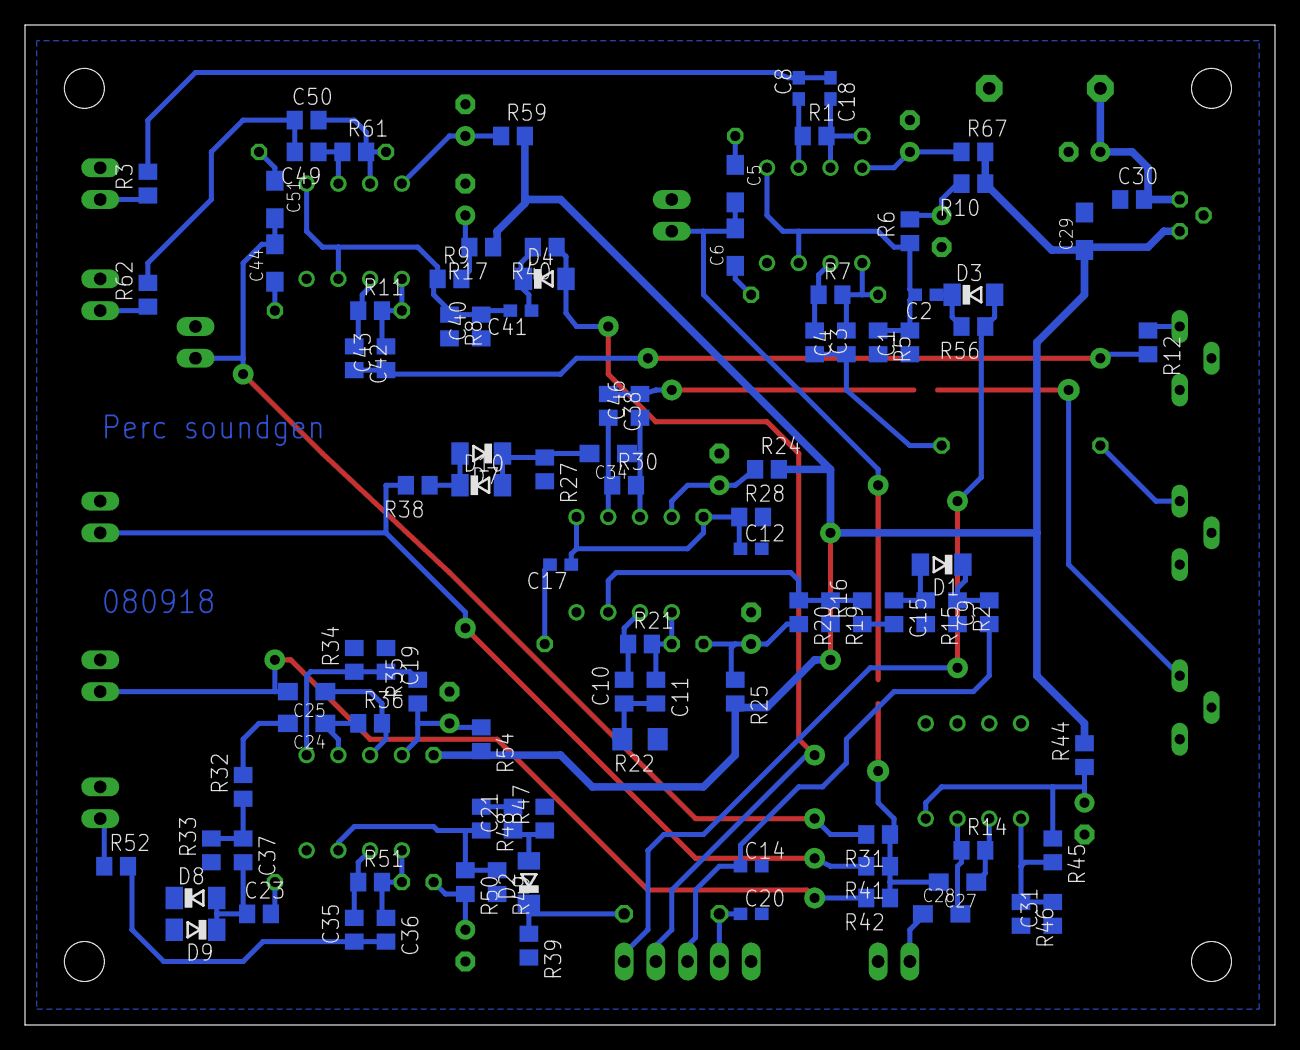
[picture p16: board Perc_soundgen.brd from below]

Board: 2 copper layers, 100.0 x 80.0 mm, 140 parts (98 on the bottom side), 79 nets.

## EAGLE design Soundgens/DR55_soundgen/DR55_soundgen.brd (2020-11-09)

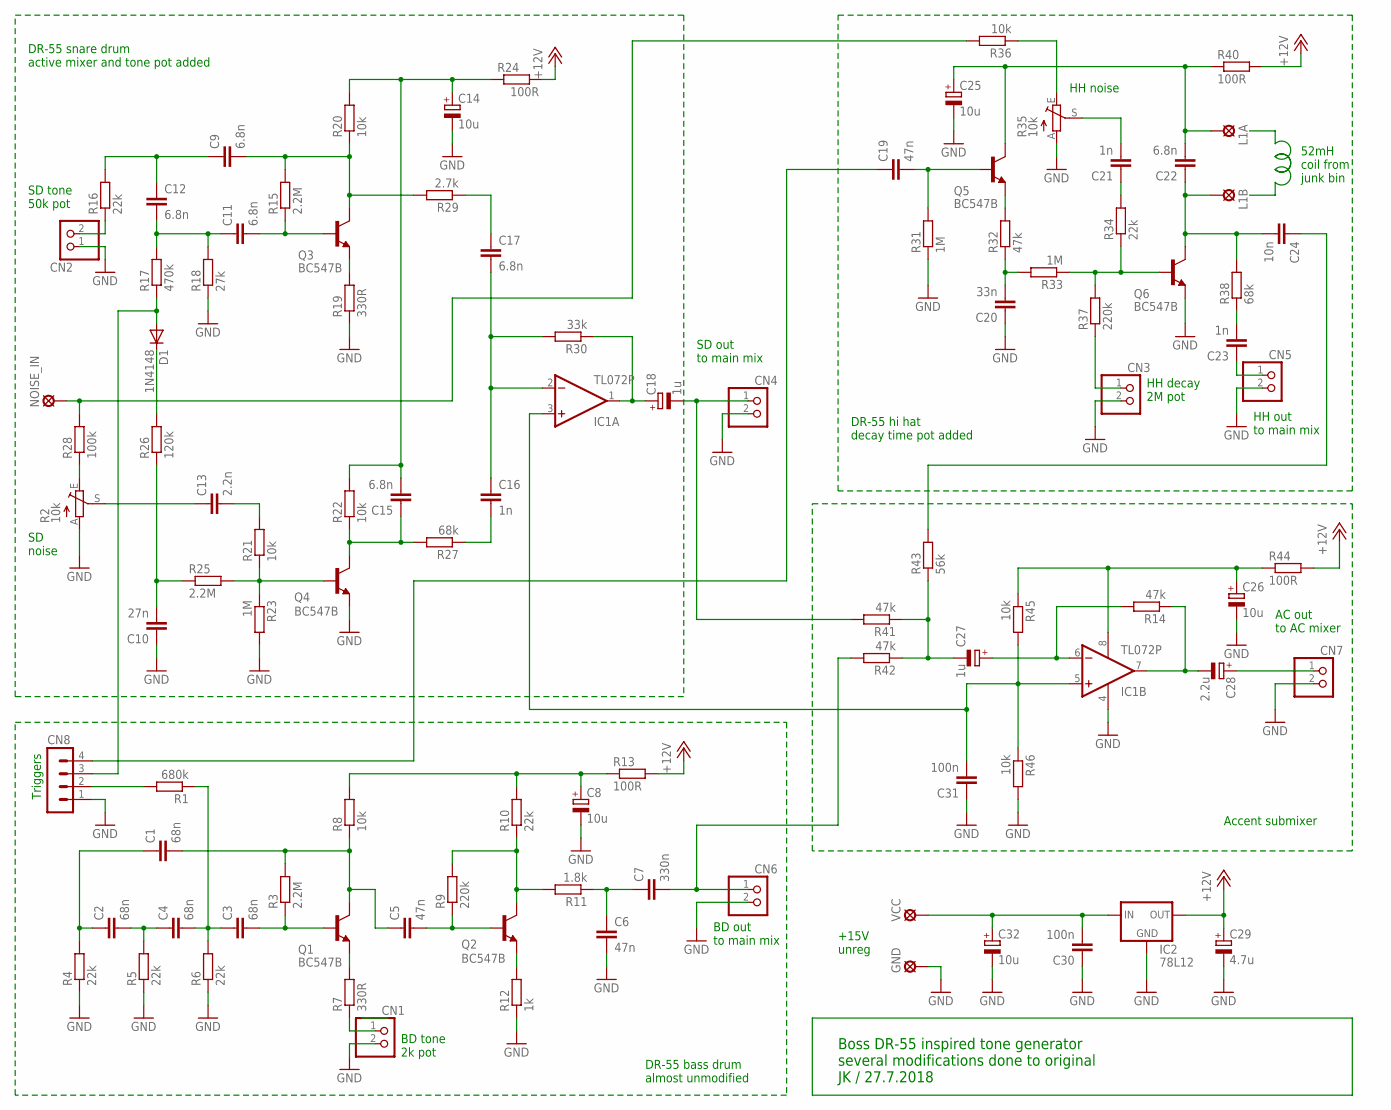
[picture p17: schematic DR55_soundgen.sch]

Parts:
C1, C2, C3, C4: 68n; C0805
C5, C6, C19: 47n; C0805
C7: 330n; C0805
C8, C14, C25, C26, C32: 10u; E5-5
C9, C11, C12, C17, C22: 6.8n; C0805
C10: 27n; C0805
C13: 2.2n; C0805
C15: 6.8n; C025-024X044
C16, C21, C23: 1n; C0805
C18, C27: 1u; SMC_A
C20: 33n; C0805
C24: 10n; C0805
C28: 2.2u; E5-5
C29: 4.7u; SMC_A
C30, C31: 100n; C0805
CN1, CN2, CN3, CN4, CN5, CN6, CN7: PINHD-1X2; 1X02
CN8: MA04-1
D1: 1N4148; SOD80C
GND: LSP10
IC1: TL072P; DIL08
IC2: 78L12; 78LXX
L1A, L1B: MCS10B
NOISE_IN: LSP10
Q1, Q2, Q3, Q4, Q5, Q6: BC547B; TO92
R1: 680k; R0805
R2, R35: 10k; S63X
R3, R15, R25: 2.2M; R0805
R4, R5, R6, R10, R16, R34: 22k; R0805
R7, R19: 330R; R0805
R8, R20, R21, R22, R36, R45, R46: 10k; R0805
R9, R37: 220k; R0805
R11: 1.8k; R0805
R12: 1k; R0805
R13, R24, R40, R44: 100R; R0805
R14, R41, R42: 47k; R0805
R17: 470k; R0805
R18: 27k; R0805
R23, R31, R33: 1M; R0805
R26: 120k; R0805
R27, R38: 68k; R0805
R28: 100k; R0805
R29: 2.7k; R0805
R30: 33k; R0805
R32: 47k; 0207/10
R43: 56k; R0805
VCC: LSP10

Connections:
+12V: C29.+, IC2.OUT, R13.2, R24.2, R40.2, R44.2
+15V: C30.2, C32.+, IC2.IN, VCC.MP
GND: C6.2, C8.-, C10.1, C14.-, C20.1, C25.-, C26.-, C29.-, C30.1, C31.1, C32.-, CN1.2, CN2.1, CN3.2, CN4.2, CN5.2, CN6.2, CN7.2, CN8.1, GND.MP, IC1.4 (V-), IC2.GND, Q4.1 (E), Q6.1 (E), R2.A, R4.1, R5.1, R6.1, R12.1, R18.1, R19.1, R23.2, R31.1, R35.A, R46.2
unnamed: C1.1, C2.1, R4.2
unnamed: C2.2, C4.1, R5.2
unnamed: C3.1, C4.2, R1.1, R6.2
unnamed: C3.2, Q1.2 (B), R3.1
unnamed: Q1.1 (E), R7.2
unnamed: CN1.1, R7.1
unnamed: C1.2, C5.1, Q1.3 (C), R3.2, R8.1
unnamed: C9.1, C12.1, R16.2
unnamed: C5.2, Q2.2 (B), R9.1
unnamed: R2.E, R28.1
unnamed: Q2.3 (C), R9.2, R10.1, R11.2
unnamed: Q2.1 (E), R12.2
unnamed: C6.1, C7.1, R11.1
unnamed: C11.1, C12.2, R17.2, R18.2
unnamed: C11.2, Q3.2 (B), R15.1
unnamed: Q3.1 (E), R19.2
unnamed: CN2.2, R16.1
unnamed: C9.2, Q3.3 (C), R15.2, R20.1, R29.2
unnamed: D1.C, R26.2
unnamed: C15.1, Q4.3 (C), R22.1, R27.2
unnamed: C10.2, R25.1, R26.1
unnamed: Q4.2 (B), R21.1, R23.1, R25.2
unnamed: C13.2, R21.2
unnamed: C16.2, R27.1
unnamed: C19.2, Q5.2 (B), R31.2
unnamed: C13.1, R2.S
unnamed: C17.1, R29.1
unnamed: C16.1, C17.2, IC1.2 (-IN), R30.2
unnamed: Q5.1 (E), R32.2
unnamed: C18.+, IC1.1 (OUT), R30.1
unnamed: C20.2, R32.1, R33.2
unnamed: Q6.2 (B), R33.1, R34.1, R37.2
unnamed: CN3.1, R37.1
unnamed: C22.1, C24.2, L1B.MP, Q6.3 (C), R38.2
unnamed: C23.2, R38.1
unnamed: C21.1, R34.2
unnamed: C21.2, R35.S
unnamed: R35.E, R36.1
unnamed: C27.-, R41.1, R42.1, R43.1
unnamed: C28.-, IC1.7 (OUT), R14.1
unnamed: C27.+, IC1.6 (-IN), R14.2
NOISE_IN: NOISE_IN.MP, R28.2, R36.2
OUT_AC: C28.+, CN7.1
OUT_BD: C7.2, CN6.1, R42.2
OUT_HH: C23.1, CN5.1
OUT_HH_AC: C24.1, R43.2
OUT_SD: C18.-, CN4.1, R41.2
TRIG_BD: CN8.2, R1.2
TRIG_HH: C19.1, CN8.4
TRIG_SD: CN8.3, D1.A, R17.1
V_BD: C8.+, R8.2, R10.2, R13.1
V_HH: C22.2, C25.+, L1A.MP, Q5.3 (C), R40.1
V_MX: C26.+, IC1.8 (V+), R44.1, R45.1
V_MX/2: C31.2, IC1.3 (+IN), IC1.5 (+IN), R45.2, R46.1
V_SD: C14.+, C15.2, R20.2, R22.2, R24.1

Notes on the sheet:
52mH coil from junk bin
Triggers
BD tone 2k pot
SD tone 50k pot
HH decay 2M pot
HH out to main mix
AC out to AC mixer
BD out to main mix
SD out to main mix
+15V unreg
DR-55 bass drum almost unmodified
DR-55 snare drum active mixer and tone pot added
DR-55 hi hat decay time pot added
Accent submixer
Boss DR-55 inspired tone generator several modifications done to original JK / 27.7.2018
HH noise
SD noise

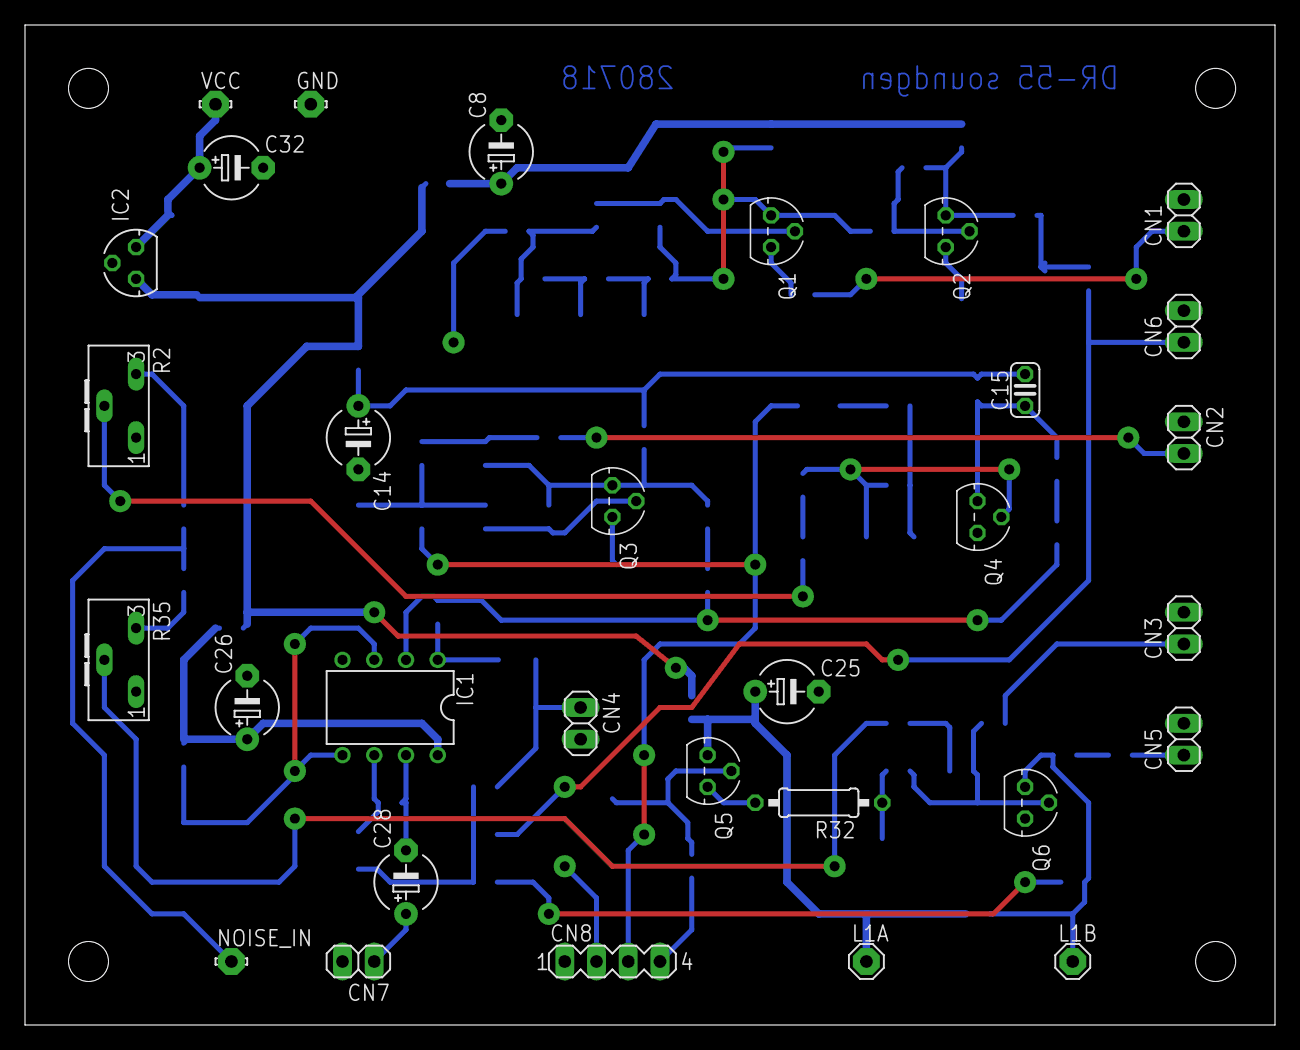
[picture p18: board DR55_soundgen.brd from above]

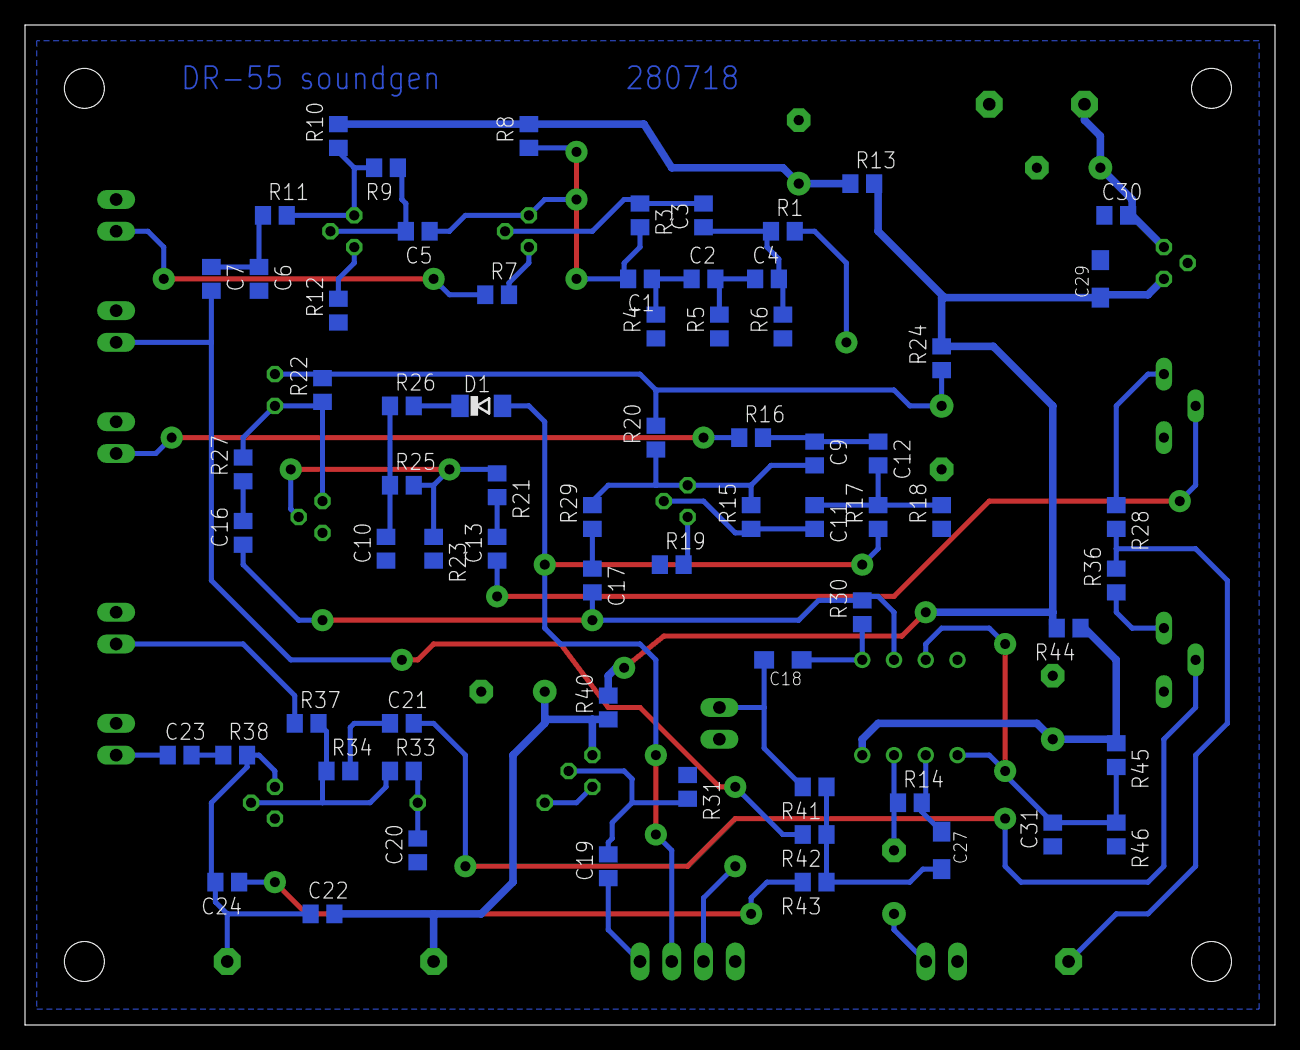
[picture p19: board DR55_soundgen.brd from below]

Board: 2 copper layers, 100.0 x 80.0 mm, 99 parts (68 on the bottom side), 58 nets.

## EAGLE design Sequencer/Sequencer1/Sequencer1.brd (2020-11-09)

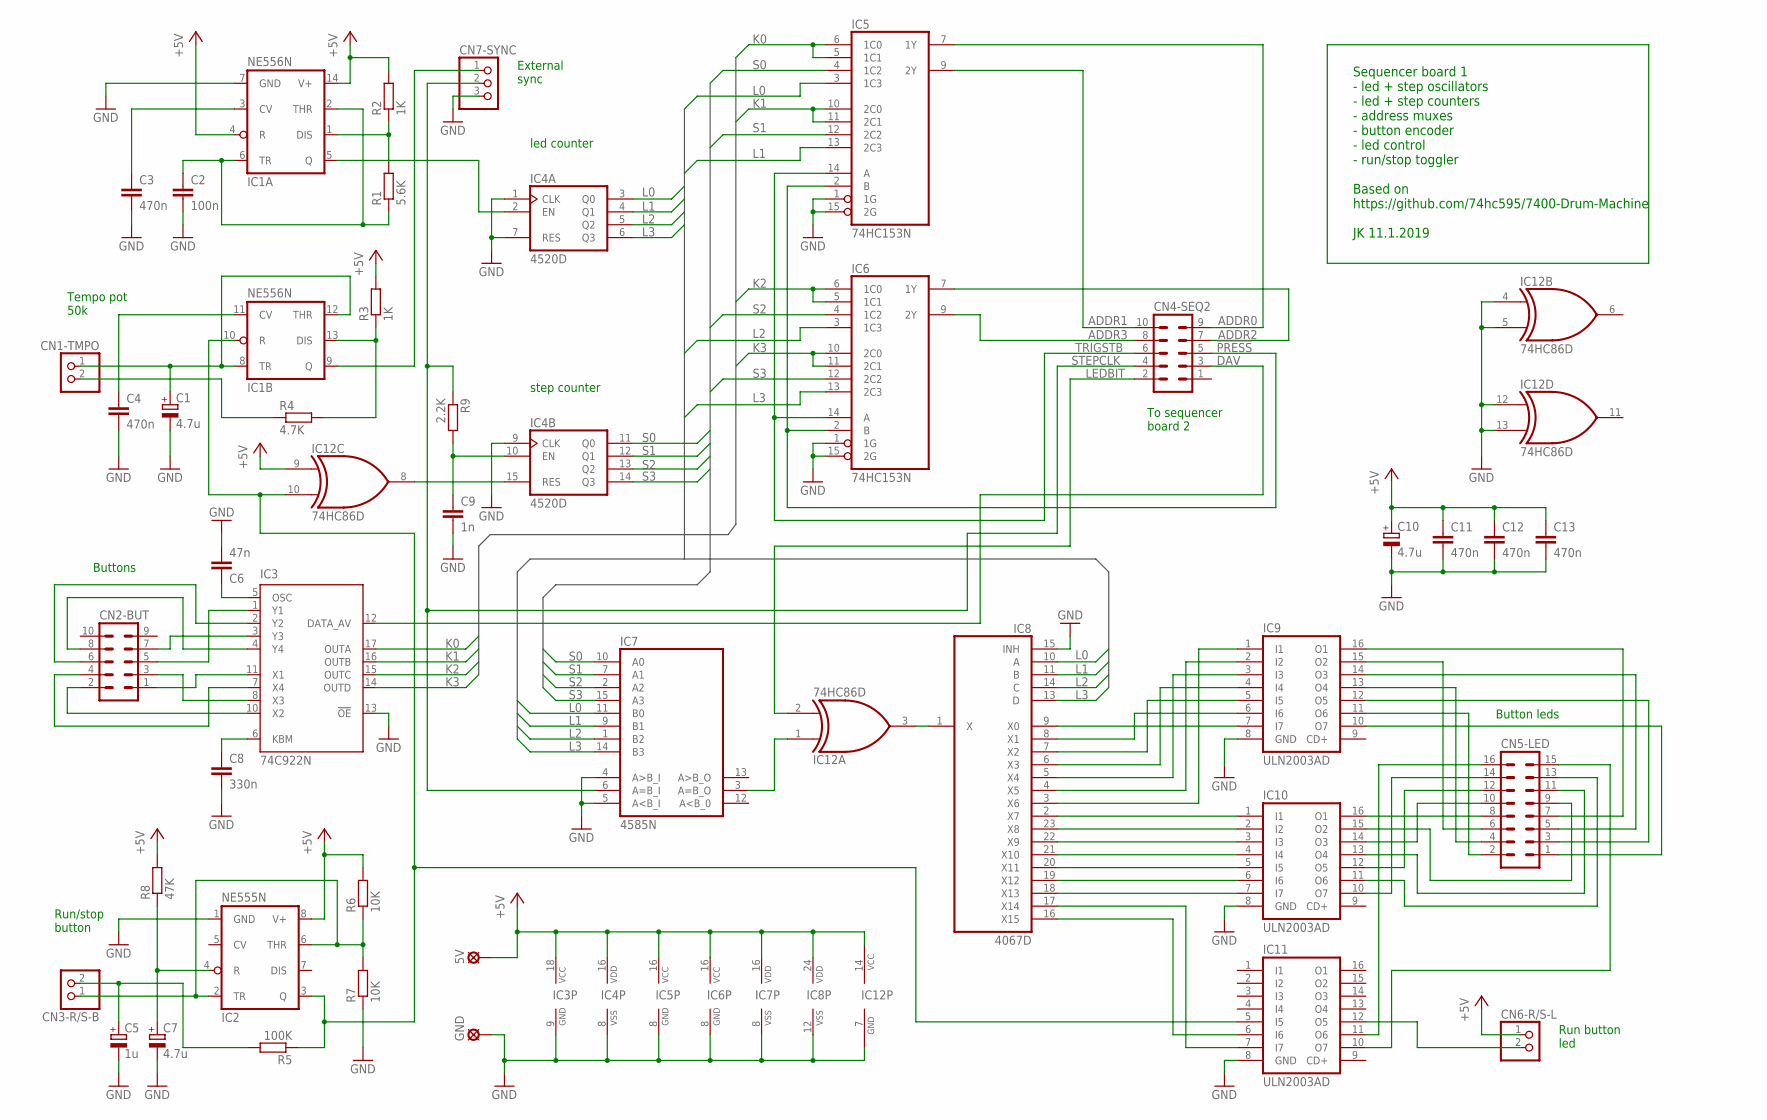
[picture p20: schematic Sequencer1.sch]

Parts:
5V: LSP10
C1, C7, C10: 4.7u; SMC_A
C2: 100n; C0805
C3, C4, C11, C12, C13: 470n; C0603
C5: 1u; SMC_A
C6: 47n; C0805
C8: 330n; C0805
C9: 1n; C0805
CN1-TMPO, CN3-R/S-B, CN6-R/S-L: PINHD-1X2; 1X02
CN2-BUT, CN4-SEQ2: MA05-2
CN5-LED: MA08-2
CN7-SYNC: PINHD-1X3; 1X03
GND: LSP10
IC1: NE556N; DIL14
IC2: NE555N; DIL08
IC3: 74C922N; DIL18
IC4: 4520D; SO16
IC5, IC6: 74HC153N; DIL16
IC7: 4585N; DIL16
IC8: 4067D; SO24W
IC9, IC10, IC11: ULN2003AD; SO16
IC12: 74HC86D; SO14
R1: 5.6K; R0805
R2, R3: 1K; R0805
R4: 4.7K; R0805
R5: 100K; R0805
R6, R7: 10K; R0805
R8: 47K; R0805
R9: 2.2K; R0805

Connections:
!PRESS: CN4-SEQ2.5, IC5.2 (B), IC6.2 (B)
!RUN: IC4.15 (RES), IC12.8 (O)
+5V: 5V.MP, C10.+, C11.1, C12.1, C13.1, CN6-R/S-L.1, IC1.4 (R), IC1.14 (V+), IC2.8 (V+), IC3.18 (VCC), IC4.16 (VDD), IC5.16 (VCC), IC6.16 (VCC), IC7.16 (VDD), IC8.24 (VDD), IC12.9 (I0), IC12.14 (VCC), R2.2, R3.2, R6.2, R8.2
ADDR0: CN4-SEQ2.9, IC5.7 (1Y)
ADDR1: CN4-SEQ2.10, IC5.9 (2Y)
ADDR2: CN4-SEQ2.7, IC6.7 (1Y)
ADDR3: CN4-SEQ2.8, IC6.9 (2Y)
DAV: CN4-SEQ2.3, IC3.12 (DATA_AV)
GND: C1.-, C2.2, C3.2, C4.2, C5.-, C6.2, C7.-, C8.2, C9.2, C10.-, C11.2, C12.2, C13.2, CN7-SYNC.3, GND.MP, IC1.7 (GND), IC2.1 (GND), IC3.9 (GND), IC3.13 (!OE), IC4.1 (CLK), IC4.7 (RES), IC4.8 (VSS), IC4.9 (CLK), IC5.1 (1G), IC5.8 (GND), IC5.15 (2G), IC6.1 (1G), IC6.8 (GND), IC6.15 (2G), IC7.4 (A>B_I), IC7.5 (A<B_I), IC7.8 (VSS), IC8.12 (VSS), IC8.15 (INH), IC9.8 (GND), IC10.8 (GND), IC11.8 (GND), IC12.4 (I0), IC12.5 (I1), IC12.7 (GND), IC12.12 (I0), IC12.13 (I1), R7.1
K0: IC3.17 (OUTA), IC5.5 (1C1), IC5.6 (1C0)
K1: IC3.16 (OUTB), IC5.10 (2C0), IC5.11 (2C1)
K2: IC3.15 (OUTC), IC6.5 (1C1), IC6.6 (1C0)
K3: IC3.14 (OUTD), IC6.10 (2C0), IC6.11 (2C1)
L0: IC4.3 (Q0), IC5.3 (1C3), IC7.11 (B0), IC8.10 (A)
L1: IC4.4 (Q1), IC5.13 (2C3), IC7.9 (B1), IC8.11 (B)
L2: IC4.5 (Q2), IC6.3 (1C3), IC7.1 (B2), IC8.14 (C)
L3: IC4.6 (Q3), IC6.13 (2C3), IC7.14 (B3), IC8.13 (D)
LED0: CN5-LED.1, IC9.10 (O7)
LED1: CN5-LED.2, IC9.11 (O6)
LED2: CN5-LED.3, IC9.12 (O5)
LED3: CN5-LED.4, IC9.13 (O4)
LED4: CN5-LED.5, IC9.14 (O3)
LED5: CN5-LED.6, IC9.15 (O2)
LED6: CN5-LED.7, IC9.16 (O1)
LED7: CN5-LED.8, IC10.16 (O1)
LED8: CN5-LED.9, IC10.15 (O2)
LED9: CN5-LED.10, IC10.14 (O3)
LED10: CN5-LED.11, IC10.13 (O4)
LED11: CN5-LED.12, IC10.12 (O5)
LED12: CN5-LED.13, IC10.11 (O6)
LED13: CN5-LED.14, IC10.10 (O7)
LED14: CN5-LED.15, IC11.10 (O7)
LED15: CN5-LED.16, IC11.11 (O6)
LEDBIT: CN4-SEQ2.2, IC12.2 (I1)
LEDCLK: IC1.5 (Q), IC4.2 (EN)
unnamed: C3.1, IC1.3 (CV)
unnamed: C2.1, IC1.2 (THR), IC1.6 (TR), R1.1
unnamed: C1.+, CN1-TMPO.1, IC1.8 (TR), IC1.12 (THR)
unnamed: IC1.1 (DIS), R1.2, R2.1
unnamed: C4.1, IC1.11 (CV)
unnamed: CN1-TMPO.2, R4.1
unnamed: IC1.13 (DIS), R3.1, R4.2
unnamed: CN3-R/S-B.1, IC2.2 (TR), IC2.6 (THR), R6.1, R7.2
unnamed: C8.1, IC3.6 (KBM)
unnamed: C6.1, IC3.5 (OSC)
unnamed: C5.+, CN3-R/S-B.2, R5.2
unnamed: IC8.9 (X0), IC9.7 (I7)
unnamed: IC8.7 (X2), IC9.5 (I5)
unnamed: C7.+, IC2.4 (R), R8.1
unnamed: IC8.6 (X3), IC9.4 (I4)
unnamed: IC8.5 (X4), IC9.3 (I3)
unnamed: IC8.4 (X5), IC9.2 (I2)
unnamed: C9.1, IC4.10 (EN), R9.2
unnamed: IC8.3 (X6), IC9.1 (I1)
unnamed: IC8.2 (X7), IC10.1 (I1)
unnamed: IC8.23 (X8), IC10.2 (I2)
unnamed: IC8.22 (X9), IC10.3 (I3)
unnamed: IC8.21 (X10), IC10.4 (I4)
unnamed: IC8.20 (X11), IC10.5 (I5)
unnamed: IC8.19 (X12), IC10.6 (I6)
unnamed: IC8.18 (X13), IC10.7 (I7)
unnamed: IC8.17 (X14), IC11.7 (I7)
unnamed: IC8.16 (X15), IC11.6 (I6)
unnamed: IC8.1 (X), IC12.3 (O)
unnamed: IC7.3 (A=B_O), IC12.1 (I0)
unnamed: IC8.8 (X1), IC9.6 (I6)
RUN: IC1.10 (R), IC2.3 (Q), IC11.5 (I5), IC12.10 (I1), R5.1
RUNLED: CN6-R/S-L.2, IC11.12 (O5)
S0: IC4.11 (Q0), IC5.4 (1C2), IC7.10 (A0)
S1: IC4.12 (Q1), IC5.12 (2C2), IC7.7 (A1)
S2: IC4.13 (Q2), IC6.4 (1C2), IC7.2 (A2)
S3: IC4.14 (Q3), IC6.12 (2C2), IC7.15 (A3)
STEPCLK: CN4-SEQ2.4, CN7-SYNC.2, IC7.6 (A=B_I), R9.1
STEPCLK_OUT: CN7-SYNC.1, IC1.9 (Q)
TRIGSTB: CN4-SEQ2.6, IC5.14 (A), IC6.14 (A)
X1: CN2-BUT.1, IC3.11 (X1)
X2: CN2-BUT.2, IC3.10 (X2)
X3: CN2-BUT.3, IC3.8 (X3)
X4: CN2-BUT.4, IC3.7 (X4)
Y1: CN2-BUT.5, IC3.1 (Y1)
Y2: CN2-BUT.6, IC3.2 (Y2)
Y3: CN2-BUT.7, IC3.3 (Y3)
Y4: CN2-BUT.8, IC3.4 (Y4)

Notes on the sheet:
Tempo pot 50k
Buttons
Run/stop button
To sequencer board 2
Button leds
Run button led
Sequencer board 1 - led + step oscillators - led + step counters - address muxes - button encoder - led control - run/stop toggler Based on https://github.com/74hc595/7400-Drum-Machine JK 11.1.2019
led counter
step counter
External sync

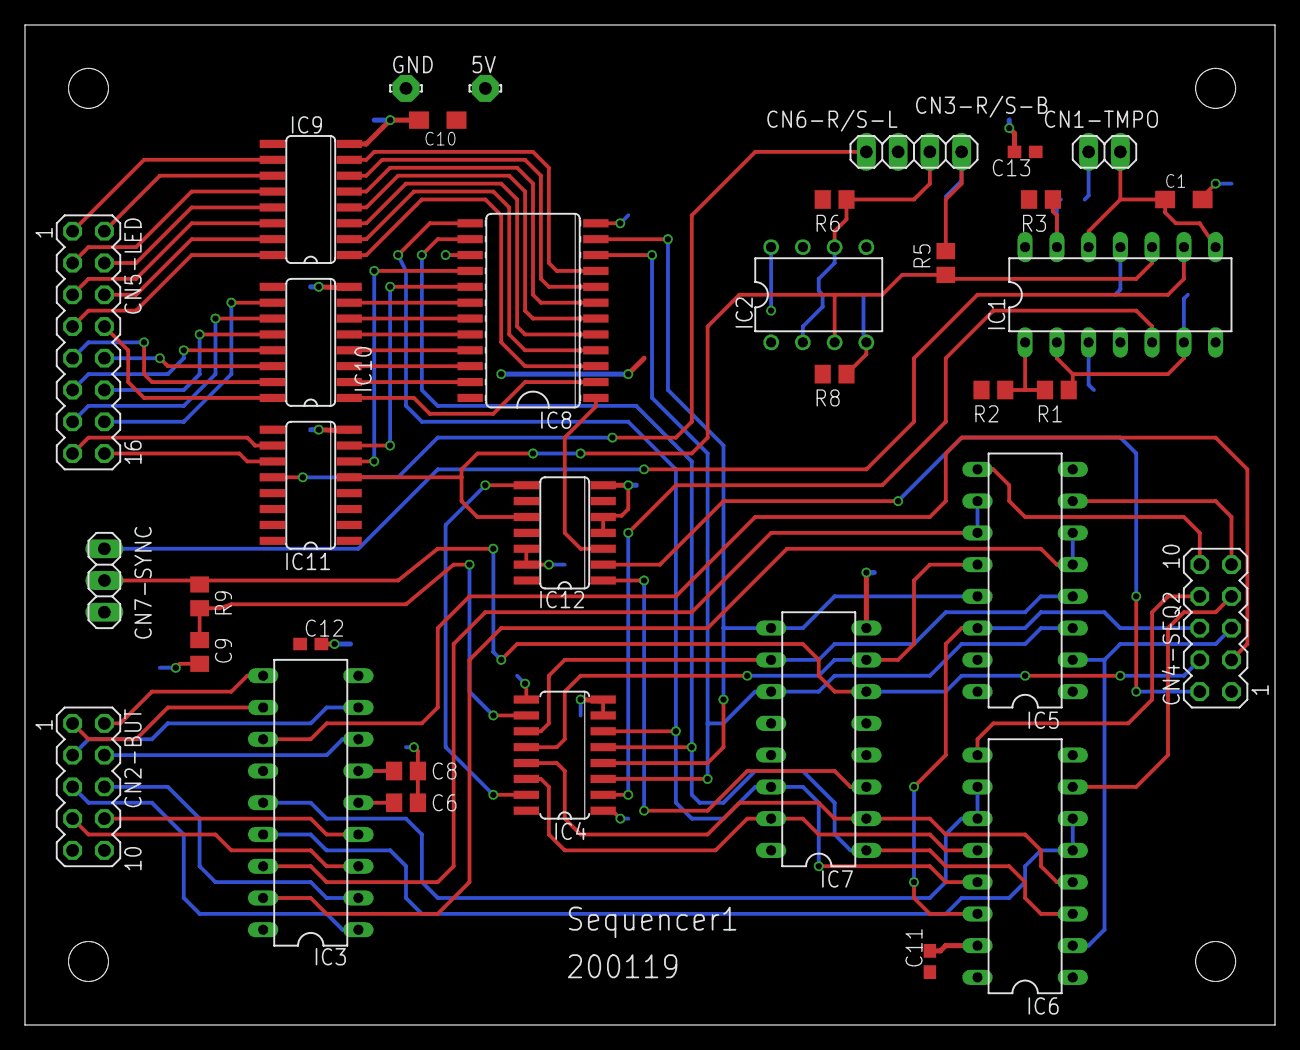
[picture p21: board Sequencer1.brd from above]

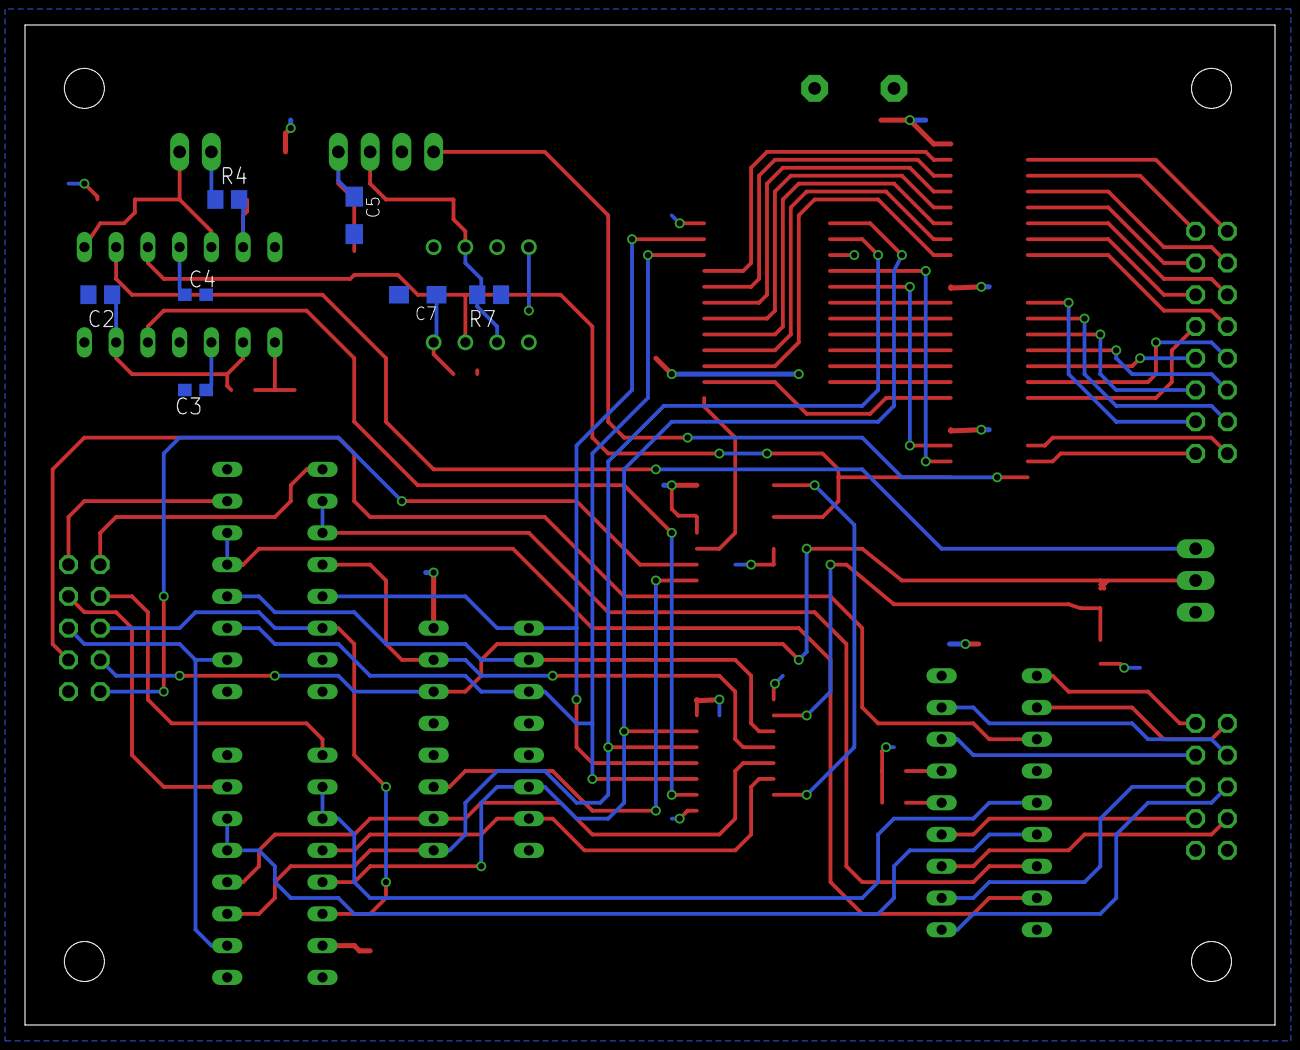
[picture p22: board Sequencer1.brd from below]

Board: 2 copper layers, 100.0 x 80.0 mm, 43 parts (7 on the bottom side), 83 nets.

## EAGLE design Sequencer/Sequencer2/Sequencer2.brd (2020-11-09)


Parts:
5V-OUT: LSP10
C1: 4.7u; SMC_A
C2, C3, C6: 220p; C0805
C4: 47p; C0805
C5: 100n; C0805
C7, C8, C9, C10, C11: 470n; C0603
CN1-CHSW, CN4-SEQ1, CN5-TRIG: MA05-2
CN2-BANK: MA03-1
CN3-CLR: PINHD-1X2; 1X02
GND1, GND2: LSP10
IC1, IC2: 4538N; DIL16
IC3, IC4: 74HC175D; SO16
IC5: 4051D; SO16
IC6: 74HC148N; DIL16
IC7, IC8: 74HC86D; SO14
IC9: 74HC563N; DIL20
IC10: 74HC00D; SO14
IC11: MK48Z02; DIL24-6
IC12: 7805TV; TO220V
R1, R4, R6: 4.7K; R0805
R2: 200K; S63X
R3: 2.7K; R0805
R5: 47K; R0805
R7, R8, R9: 10K; R0805
RN1: 22K; SIL10
RN2: 10K; SIL9
VIN: LSP10

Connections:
!BD: CN5-TRIG.2, IC3.3 (!Q1)
!MEMW: IC1.9 (!Q), IC9.1 (OC), IC9.11 (C), IC10.1 (I0)
!PRESS: CN4-SEQ1.5, IC1.7 (!Q)
!RSCL: CN5-TRIG.8, IC4.6 (!Q2)
!SD: CN5-TRIG.4, IC3.6 (!Q2)
+5V: 5V-OUT.MP, C7.1, C8.1, C9.1, C10.1, C11.1, IC1.3 (CD), IC1.5 (B), IC1.11 (B), IC1.13 (CD), IC1.16 (VDD), IC2.3 (CD), IC2.13 (CD), IC2.16 (VDD), IC3.16 (VCC), IC4.16 (VCC), IC5.16 (VCC), IC6.16 (VCC), IC7.14 (VCC), IC8.14 (VCC), IC9.2 (1D), IC9.20 (VCC), IC10.14 (VCC), IC11.24 (VCC), IC12.3 (VO), R1.2, R2.E, R2.S, R4.2, R6.2, R7.2, R8.2, R9.2, RN2.1
AC: CN5-TRIG.9, IC4.10 (Q3)
ADDR0: CN4-SEQ1.9, IC11.8 (A0)
ADDR1: CN4-SEQ1.10, IC11.7 (A1)
ADDR2: CN4-SEQ1.7, IC11.6 (A2)
ADDR3: CN4-SEQ1.8, IC11.5 (A3)
BD: CN5-TRIG.1, IC3.2 (Q1)
CH0: IC5.11 (A), IC6.9 (A0)
CH1: IC5.10 (B), IC6.7 (A1)
CH2: IC5.9 (C), IC6.6 (A2)
D0: IC3.4 (D1), IC5.13 (X0), IC8.1 (I0), IC9.17 (3Q), IC11.9 (I/O1), RN1.8
D1: IC3.5 (D2), IC5.14 (X1), IC8.4 (I0), IC9.15 (5Q), IC11.10 (I/O2), RN1.6
D2: IC3.12 (D3), IC5.15 (X2), IC8.9 (I0), IC9.14 (6Q), IC11.11 (I/O3), RN1.5
D3: IC3.13 (D4), IC5.12 (X3), IC7.12 (I0), IC9.12 (8Q), IC11.13 (I/O4), RN1.3
D4: IC4.4 (D1), IC5.1 (X4), IC7.1 (I0), IC9.13 (7Q), IC11.14 (I/O5), RN1.4
D5: IC4.5 (D2), IC5.5 (X5), IC7.4 (I0), IC9.16 (4Q), IC11.15 (I/O6), RN1.7
D6: IC4.12 (D3), IC5.2 (X6), IC8.12 (I0), IC9.18 (2Q), IC11.16 (I/O7), RN1.9
D7: IC9.19 (1Q), IC11.17 (I/O8), RN1.10
DAV: CN4-SEQ1.3, IC1.4 (A)
GND: C1.-, C3.1, C7.2, C8.2, C9.2, C10.2, C11.2, CN1-CHSW.8, CN2-BANK.2, CN3-CLR.2, CN5-TRIG.10, GND1.MP, GND2.MP, IC1.8 (VSS), IC2.4 (A), IC2.8 (VSS), IC2.12 (A), IC3.8 (GND), IC4.8 (GND), IC4.13 (D4), IC5.4 (X7), IC5.6 (INH), IC5.7 (VEE), IC5.8 (GND), IC6.5 (EI), IC6.8 (GND), IC7.7 (GND), IC7.9 (I0), IC7.10 (I1), IC8.7 (GND), IC9.10 (GND), IC10.7 (GND), IC10.9 (I0), IC10.10 (I1), IC10.12 (I0), IC10.13 (I1), IC11.1 (A7), IC11.2 (A6), IC11.12 (GND), IC11.18 (!CS), IC11.19 (A10), IC11.22 (A9), IC11.23 (A8), IC12.2 (GND), RN1.1
HH: CN5-TRIG.5, IC3.10 (Q3)
HT: CN5-TRIG.7, IC4.2 (Q1)
LEDBIT: CN4-SEQ1.2, IC5.3 (X)
LT: CN5-TRIG.6, IC3.15 (Q4)
unnamed: C5.2, IC2.1 (T1)
unnamed: C5.1, IC2.2 (T2), R5.1
unnamed: C2.2, IC1.1 (T1)
unnamed: C2.1, IC1.2 (T2), R1.1
unnamed: IC1.6 (Q), R3.2
unnamed: C3.2, IC1.12 (A), R3.1
unnamed: C4.2, IC1.14 (T2), R4.1
unnamed: C4.1, IC1.15 (T1)
unnamed: R2.A, R5.2
unnamed: C6.2, IC2.15 (T1)
unnamed: C6.1, IC2.14 (T2), R6.1
unnamed: IC8.3 (O), IC9.4 (3D)
unnamed: IC8.6 (O), IC9.6 (5D)
unnamed: IC8.8 (O), IC9.7 (6D)
unnamed: IC7.11 (O), IC9.9 (8D)
unnamed: IC7.3 (O), IC9.8 (7D)
unnamed: IC7.6 (O), IC9.5 (4D)
unnamed: IC8.11 (O), IC9.3 (2D)
unnamed: CN2-BANK.1, IC11.3 (A5), R9.1
unnamed: CN3-CLR.1, IC10.2 (I1), R7.1
unnamed: C1.+, IC12.1 (VI), VIN.MP
unnamed: CN2-BANK.3, IC11.4 (A4), R8.1
unnamed: IC10.3 (O), IC10.4 (I0), IC10.5 (I1), IC11.20 (!OE)
unnamed: IC10.6 (O), IC11.21 (!WE)
SD: CN5-TRIG.3, IC3.7 (Q2)
STEPCLK: CN4-SEQ1.4, IC2.5 (B), IC2.11 (B)
SW0: CN1-CHSW.1, IC6.4 (7), IC8.2 (I1), RN2.5
SW1: CN1-CHSW.2, IC6.3 (6), IC8.5 (I1), RN2.4
SW2: CN1-CHSW.3, IC6.2 (5), IC8.10 (I1), RN2.3
SW3: CN1-CHSW.4, IC6.1 (4), IC7.13 (I1), RN2.2
SW4: CN1-CHSW.5, IC6.13 (3), IC7.2 (I1), RN2.6
SW5: CN1-CHSW.6, IC6.12 (2), IC7.5 (I1), RN2.7
SW6: CN1-CHSW.7, IC6.11 (1), IC8.13 (I1), RN2.8
SW7: IC6.10 (0), RN2.9
TRIGCLR: IC2.6 (Q), IC3.1 (CLR), IC4.1 (CLR)
TRIGSTB: CN4-SEQ1.6, IC2.9 (!Q), IC3.9 (CLK), IC4.9 (CLK)

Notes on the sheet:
D0 = BD D1 = SD D2 = HH D3 = LT D4 = HT D5 = RS/CL D6 = AC
Trig pulse length
Channel select switch
Bank select switch
CLR button
5V to sequencer1 board
Triggers to sound generators
To sequencer1 board
15V unregulated
Sequencer2 - memory + latch - XORs - chan encoder + mux - pulse generators - trigger flip-flops



Board: 2 copper layers, 100.0 x 80.0 mm, 43 parts (4 on the bottom side), 65 nets.

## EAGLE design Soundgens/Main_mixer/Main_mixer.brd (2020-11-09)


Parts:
C1, C5, C7, C8, C28, C29, C38: 4.7u; SMC_A
C2: 220n; C0805
C3, C4: 22u; E5-5
C6, C34: 1u; SMC_A
C26, C32, C39: 10u; E2,5-5
C30: 100n; C0805
C31: 330n; C0805
CN1, CN2, CN3, CN4, CN5, CN6, CN7, CN8, CN11, CN12, CN13, CN14, CN15: PINHD-1X2; 1X02
D1, D3: 1N4148; SOD80C
GND: LSP10
IC1, IC3: TL072P; DIL08
IC2: 78L12; 78LXX
NOISE_OUT1, NOISE_OUT2: LSP10
Q1: J112; TO92
Q2: BC108B; TO18
R1, R47: 100k; R0805
R3: 68k; R0805
R4, R9: 1k; R0805
R5: 2.2M; R0805
R6: 22k; R0805
R7: 220k; R0805
R8, R13, R17, R23, R41: 33k; R0805
R10: 470k; R0805
R11, R12, R18, R19, R21: 39k; R0805
R14, R42, R43: 47k; R0805
R15: 200k; S63X
R20: 56k; R0805
R22: 3.3k; R0805
R25: 1M; S63X
R39: 1M; R0805
R44, R54: 100R; R0805
R45, R46, R49, R50: 10k; R0805
VCC: LSP10

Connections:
+12V: C29.+, IC2.OUT, R6.1, R7.1, R44.2, R54.2
+15V: C30.2, C32.+, IC2.IN, VCC.MP
GND: C2.1, C3.-, C4.-, C26.-, C29.-, C30.1, C31.1, C32.-, C34.-, C39.-, CN1.2, CN2.2, CN3.2, CN4.2, CN5.2, CN6.2, CN7.2, CN8.2, CN11.2, CN12.2, CN13.2, CN14.2, CN15.2, GND.MP, IC1.4 (V-), IC2.GND, IC3.4 (V-), Q2.2 (B), R8.2, R10.2, R46.2, R49.2
unnamed: C31.2, IC1.3 (+IN), IC1.5 (+IN), R45.2, R46.1
unnamed: CN6.1, R43.2
unnamed: CN2.1, R41.2
unnamed: CN3.1, R42.2
unnamed: CN4.1, D3.A
unnamed: D3.C, R9.2
unnamed: C2.2, D1.C, R9.1, R10.1
unnamed: D1.A, Q1.3 (G), R5.2
unnamed: C28.+, R1.2, R15.E
unnamed: C3.+, R1.1, R3.2, R5.1
unnamed: C8.+, R12.1, R13.1, R17.1, R18.1, R19.1, R20.1, R21.1
unnamed: R4.1, R15.A, R15.S
unnamed: Q1.1 (D), R4.2
unnamed: C1.+, Q1.2 (S)
unnamed: C1.-, CN7.1
unnamed: CN5.1, R12.2
unnamed: C4.+, R3.1, R6.2, R7.2, R8.1
unnamed: CN8.1, R13.2
unnamed: CN11.1, R17.2
unnamed: CN12.1, R18.2
unnamed: CN13.1, R19.2
unnamed: CN14.1, R20.2
unnamed: CN15.1, R21.2
unnamed: C5.+, IC1.1 (OUT), R11.1
unnamed: C5.-, CN1.1
unnamed: C7.+, IC1.6 (-IN), R14.2
unnamed: R23.2, R25.A
unnamed: C38.+, IC3.1 (OUT), R25.E, R25.S
unnamed: IC3.2 (-IN), R22.2, R23.1
unnamed: C6.-, R22.1
unnamed: C6.+, Q2.1 (E), R39.2
unnamed: C34.+, R39.1, R47.2
unnamed: C38.-, NOISE_OUT1.MP, NOISE_OUT2.MP
unnamed: C8.-, IC1.2 (-IN), R11.2
unnamed: C28.-, IC1.7 (OUT), R14.1
unnamed: C7.-, R41.1, R42.1, R43.1
unnamed: IC3.3 (+IN), R49.1, R50.1
V_BD: C39.+, IC3.8 (V+), R47.1, R50.2, R54.1
V_MX: C26.+, IC1.8 (V+), R44.1, R45.1

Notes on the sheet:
main mix out to volume pot
noise gen level
AC in from DR-55 soundgen
15V unreg
KR-55 noise generator
BD in from BD level pot
Accent mixer + modified DR-55 accent circuit
Korg KR-55 + Boss DR-55 inspired main mixer / accenter / noise generator JK / 9.12.2018
AC out to AC level pot
AC in from KR-55 soundgen
AC in from Perc soundgen
accent base level
SD in from SD level pot
HH in from HH level pot
HT in from HT level pot
LT in from LT level pot
CL/RS in from CL/RS level pot
AC in from AC level pot
Main mixer
AC trig



Board: 2 copper layers, 100.0 x 80.0 mm, 74 parts (44 on the bottom side), 42 nets.
